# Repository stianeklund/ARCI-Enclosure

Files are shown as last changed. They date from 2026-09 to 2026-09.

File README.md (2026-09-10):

# ARCI Enclosure

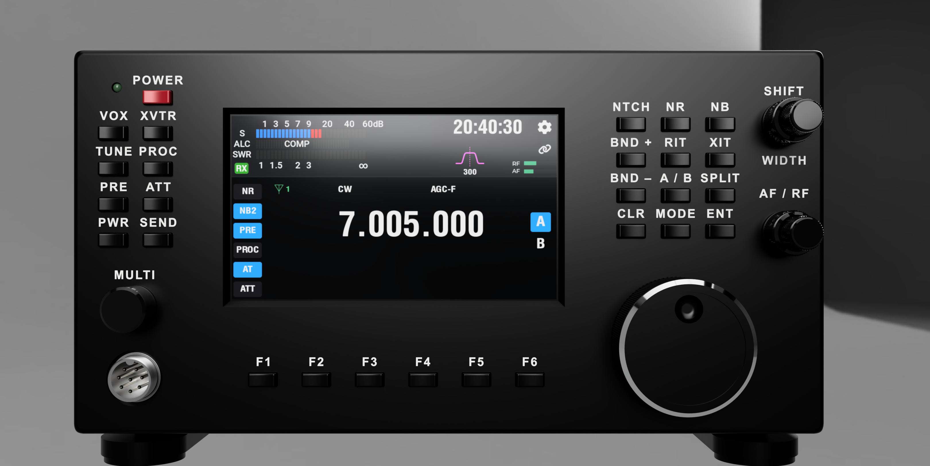
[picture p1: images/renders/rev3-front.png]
ARCI enclosure front view


ARCI Enclosure is a 3D-printable desktop control console for the
[ARCI](https://github.com/stianeklund/ARCI) amateur-radio control interface.
It holds a 5-inch touchscreen, physical controls, and rear I/O connectors.

Revision 3 uses a parametric design unlike the first prototypes which became a Fusion 360 monstrosity..
Print the main shells on a printer with a build area of at least 256 × 256 mm.

## Features

- Two-piece snap-fit enclosure with front and rear shells
- 45° beveled opening for the Waveshare 5-DSI-TOUCH-A display
- Button matrices, function buttons, and rotary encoder openings
- Label inlays for multi-material printing and printable knurled knobs
- Rear I/O openings for USB, RS-232 (DB9), and Wi-Fi/COM connectors
- Internal mounts for the ARCI PCB, display, and optional USB hub
- M3 and M5 mounting points for assembly
- Adjustable rear tilt stand with 15° click-stop increments

The rear connector layout may change.

## Key specifications

| Item | Specification |
| --- | --- |
| Overall dimensions | 254 × 130 × 54 mm |
| Minimum printer build area | 256 × 256 mm |
| Display | Waveshare 5-DSI-TOUCH-A (MIPI DSI), connected to a ESP32-P4-Wifi6 (Pico?) |
| Main controller | ARCI ESP32-S3 PCB |
| Stand adjustment | 15° increments |

## Build and files

1. Review the [bill of materials](BOM.md).
2. Follow the [printing guide](docs/printing.md).
3. Use the [tilt-stand instructions](docs/tilt-stand.md).

The printable files are in [`export/3mf`](export/3mf). Each 3MF is one
separate print part: shells, knobs, button caps, stand pieces, and mounts are
never bundled as an assembled print job. Matching neutral-CAD part files are
in [`cad/step`](cad/step).

For carry cases, accessory design, and visual fit checks, export the separate
non-printable [`ARCI_ENCLOSURE_INSPECTION.step`](cad/assembly/ARCI_ENCLOSURE_INSPECTION.step)
from the Fusion master. It contains the installed project-authored enclosure,
controls, stand, and Waveshare-compatible display replica; it is not a slicer
input and is intentionally separate from the per-part STEP files.

For the optional USB-hub parts, see the
[USB-hub parts guide](docs/right-matrix-usb-hub-shim.md).

## Display compatibility

The current release supports the Waveshare 5-DSI-TOUCH-A display. The Sunton
ESP32-8048S050C is a fit-check variant only and is not part of this release, but future releases will re-add compatability for this display type.

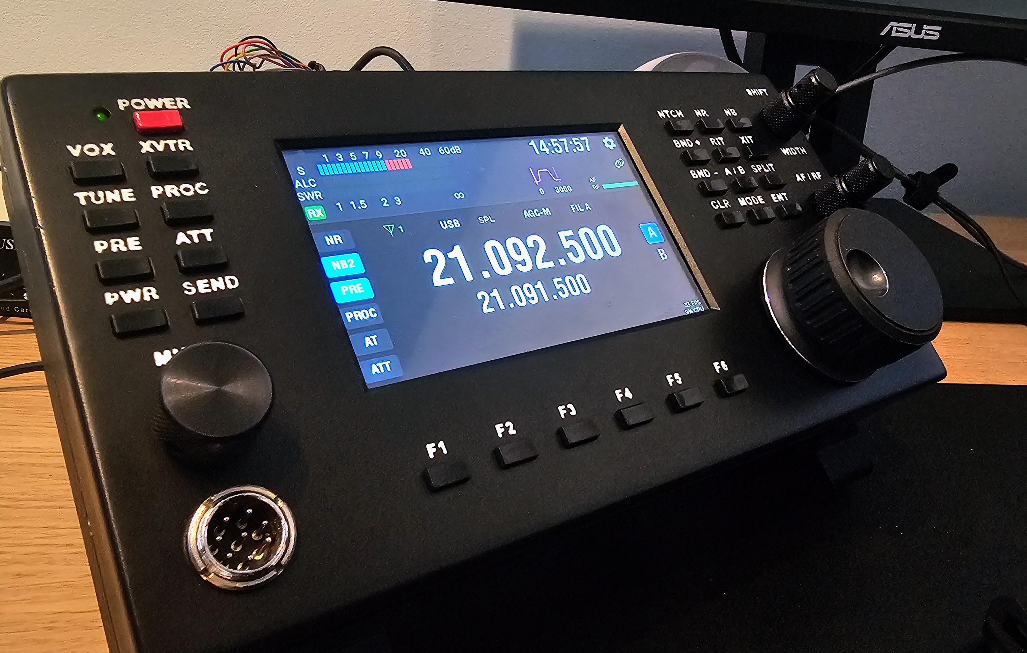
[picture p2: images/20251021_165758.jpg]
Finished enclosure


## Related projects

- [ARCI](https://github.com/stianeklund/ARCI) — firmware and CAT command router
- [ARCI-PCB](https://github.com/stianeklund/ARCI-PCB) — controller PCB
- [RemoteRadioDisplay](https://github.com/stianeklund/RemoteRadioDisplay) — display firmware

## License

This project uses the GPL-3.0 license. See [LICENSE](LICENSE) and
[NOTICE.md](NOTICE.md).

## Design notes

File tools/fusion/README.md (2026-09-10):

# Fusion 360 maintainer tools

This folder contains Fusion 360 scripts for maintainers of the ARCI enclosure.
End users normally need only the printable files in `export/3mf`, the neutral
CAD files in `cad/step`, and the project documentation.

The repository does not contain the private Fusion master. These scripts
rebuild the published parts and create the public release files.

## Before you run a rebuild

The rebuild scripts change the active Fusion document. Use a new working copy
or save a version before you run them. The scripts do not restore the model if
a later step fails.

Start with a parametric Fusion design whose name starts with `ARCI Enclosure
Rev3`. Create these empty root-level components before you run the first
script:

1. `FRONT_HALF`
2. `BACK_HALF`

The scripts expect this component structure. Do not add a body named
`FRONT_SHELL` before you run the first script.

## Install a script bundle

Every public script is a Fusion bundle: its folder contains a same-named
`.py` file and `.manifest`. In **Utilities → Add-Ins → Scripts and Add-Ins**,
open **Scripts**, click **+**, and select the script folder (not the `.py`
file). Install each required bundle once; it remains available in Fusion's
Scripts list thereafter.

## Supported rebuild sequence

Run the scripts in `rebuild/` in this order:

1. `Front_Parametric_Rebuild/`
2. `Front_Internal_Supports_Add/`
3. `Front_Panel_Caps_LED_And_Materials/`
4. `Back_Parametric_Rebuild/`
5. `Multi_Knob_Build/`
6. `Dual_Encoder_Knobs_Build/`
7. `Tilt_Stand_Build/`
8. `Stand_Hardware_Build/`

Run a complete rebuild in a new working document. Some scripts stop when they
find existing geometry. Other scripts replace their earlier script-owned
components.

`options/Build_Right_Matrix_Hub_Cradle/` creates the optional USB-hub cradle.
It is not required for the base enclosure.

## VFO dimple sizing repair

The VFO main knob belongs to the private master, rather than the supported
clean-rebuild set.  If its circular finger dimple loses its curved floor after
editing `vfoDimpleD`, add and run the `rebuild/VFO_Dimple_Parameterize` script
folder once with the master open.  Thereafter, edit only `vfoDimpleD` for ordinary sizing; the
script derives the dimple depth and floor-round radius so the cup keeps its
original 2 mm flat floor and tangent curved sides.  Use a diameter greater
than `vfoDimpleFloorD`.

## Audit and export

Install each release script separately in Fusion:

1. Open **Utilities → Add-Ins → Scripts and Add-Ins → Scripts → +**.
2. Add `release/Fusion_Timeline_Audit`.
3. Add `release/Export_Repository_Artifacts`.

Before you export, review the repository changes. The exporter replaces the
published 3MF and STEP files when it completes successfully.

1. Run `Fusion_Timeline_Audit` on the active release design.
2. Read the report in `docs/generated/fusion_timeline_audit.md`.
3. Resolve every release-gate failure.
4. Run `Export_Repository_Artifacts`.

The audit creates `docs/generated` if needed. It writes a Markdown and JSON
report there. On failure, it writes an error report in the same directory. The
exporter checks the active design again. It exports only the named public parts
in its manifest to `export/3mf` and `cad/step`.

The exporter does not export a full assembly, vendor reference geometry, or an
ECAD model. Neither release script saves the Fusion document.

## Scope and requirements

This public folder excludes private migration, experimental, quality-assurance,
and development-asset tools. Those tools are not part of the supported rebuild
or release process.

The scripts locate the repository from their own file paths. You can use any
checkout location. They require Fusion 360 and its Autodesk Fusion API
(`adsk`).

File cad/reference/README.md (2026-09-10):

# Engineering references

These files support measurement, fit checks, and historical reconstruction.
They are not production exports and are not required to print the enclosure.

- `legacy/` contains source geometry used to reconstruct the native enclosure.
- `waveshare/` contains independently modeled display reference geometry. See
  the repository [NOTICE](../../NOTICE.md) for provenance and trademark notes.

`cad/step/` contains the supported isolated-part neutral-CAD exports.
`cad/assembly/` contains separately exported, non-printable project-authored
inspection assemblies. Neither directory includes the historical references in
this folder.

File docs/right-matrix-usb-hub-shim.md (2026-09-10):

# Optional USB-hub parts

These parts support an optional internal USB hub. They are not required for the
core enclosure.

The design uses a nominal 40 × 30 × 1.6 mm hub PCB. Actual boards can differ.
Check your hub, connectors, and cables before installation.

## Available parts

| Part | Quantity | File |
| --- | ---: | --- |
| Right-matrix open cradle | 1 | [`HUB_RIGHT_MATRIX_OPEN_CRADLE_PLA.3mf`](../export/3mf/HUB_RIGHT_MATRIX_OPEN_CRADLE_PLA.3mf) |
| Upper retainer | 1 | [`HUB_RETAINER_UPPER.3mf`](../export/3mf/HUB_RETAINER_UPPER.3mf) |
| Lower retainer | 1 | [`HUB_RETAINER_LOWER.3mf`](../export/3mf/HUB_RETAINER_LOWER.3mf) |
| Rear tray | 1 | [`HUB_REAR_TRAY.3mf`](../export/3mf/HUB_REAR_TRAY.3mf) |

Select only the parts that match your installation.

## Right-matrix cradle

The cradle mounts above the right button matrix. It uses the four existing M3
mounting axes.

Two end webs connect the matrix standoffs. Side rails and transverse rails
support the hub PCB. The open center gives access to the matrix harness.

The cradle supports four hub orientations. Rotate the hub in 90° increments to
select the best cable direction.

The original orientation puts the three output ports toward the larger cable
space. It puts the USB input and power input toward the top.

## Checked clearances

| Item | Position or size |
| --- | --- |
| Matrix PCB rear face | Y = 12.72 mm |
| Matrix plug keep-out | Y = 12.72 to 23.02 mm |
| Seat-rail underside | Y = 27.70 mm |
| Hub PCB support plane | Y = 30.70 mm |
| Hub envelope | Y = 30.70 to 35.70 mm |
| Rear-cover inner surface | Approximately Y = 50.04 mm |
| Hub PCB | 40 × 30 × 1.6 mm |
| Width across USB-C plugs | 32 mm |

Clearance checks found no solid intersection at any of the four cradle
orientations. The checks included the shells, boards, carrier, hub, and cradle.

The hub envelope comes from photographs and caliper measurements. It is not a
manufacturer CAD model.

## Hardware

Use four M3 × 20 mm screws for the cradle. Check the screw engagement against
the actual matrix stack.

Use M2 fasteners for the hub-retainer positions. Select the length for your hub
board and captive nuts.

Use six M3 × 6 mm screws for the rear tray and retainers. Check the complete
hardware stack before installation.

## Printing

The cradle 3MF has its flat seat face on the build plate. The cradle does not
require generated support material.

Follow the [printing guide](printing.md) for general material and inspection
instructions.

## Files

- [Cradle STEP file](../cad/step/HUB_RIGHT_MATRIX_OPEN_CRADLE_PLA.step)
- [Assembly image](visual-reference/right-matrix-usb-hub-recessed-cradle.png)

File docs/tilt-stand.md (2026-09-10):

# Tilt stand

The stand is a pair of identical hinged supports mounted to the rear shell.
Each side uses one bracket, one support, two rubber foot pads, two M3 mounting
screws, and one M5 hinge fastener set.

## Print and prepare

Print two of each rigid part in PLA or PETG:

- [`STAND_BRACKET.3mf`](../export/3mf/STAND_BRACKET.3mf)
- [`TILT_STAND_SUPPORT.3mf`](../export/3mf/TILT_STAND_SUPPORT.3mf)

Print two of each foot pad in TPU, or replace them with suitable stick-on
rubber pads:

- [`TILT_STAND_FOOT_PAD_NEAR_HINGE.3mf`](../export/3mf/TILT_STAND_FOOT_PAD_NEAR_HINGE.3mf)
- [`TILT_STAND_FOOT_PAD_FAR_FROM_HINGE.3mf`](../export/3mf/TILT_STAND_FOOT_PAD_FAR_FROM_HINGE.3mf)

Print the bracket on its flat mounting face and the support on its foot. Ream
the hinge bores gently to 5.4 mm after printing if needed; the parts should
rotate freely before the hinge is tightened.

## Hardware per side

- 2 × M3 × 12 countersunk screws
- 1 × M5 × 30 hex bolt
- 1 × M5 washer
- 1 × M5 nyloc nut

## Assembly

1. Attach a bracket to each pair of rear-shell pilots with the two M3 screws.
2. Place the support between the bracket ears and align the serrated hinge
   faces at the desired angle.
3. Install the M5 bolt, washer, and nyloc nut. Tighten only enough to engage
   the hinge teeth securely; the support must still be adjustable.
4. Fit one near-hinge and one far foot pad to each support.

The rear shell carries the mounting bosses; neither shell requires extra
fasteners at its snap-fit joint. STEP references are available as
[`STAND_BRACKET.step`](../cad/step/STAND_BRACKET.step),
[`TILT_STAND_SUPPORT.step`](../cad/step/TILT_STAND_SUPPORT.step), and the two
separate foot-pad STEP files. This mirrors the print files: the support and
each pad are independently addressable parts, not a combined assembly export.

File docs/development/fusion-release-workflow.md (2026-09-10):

# Fusion release workflow

The editable master remains a parametric Fusion document. The public release
directories contain only release-safe artifacts: project-authored print files
in `export/3mf`, isolated neutral exchange files in `cad/step`, and an
explicitly curated project-authored inspection assembly in `cad/assembly` when
one is exported. Reference assets and unsupported maintainer tooling remain
private. Do not check in a full assembly archive: it can contain vendor and
ECAD reference models that are excluded from redistribution.

## Timeline policy

Keep the timeline in this order and collapse each group once it is complete:

1. `DATUMS AND PARAMETERS` — component origins, named planes, global user parameters.
2. `FRONT HALF - MECHANICAL` and `BACK HALF - MECHANICAL` — shell, cavity, mating interface, and panel cutouts.
3. `INTERFACES - CARRIERS AND MOUNTS` — display, hub, and electronics-specific printed parts.
4. `BACK HALF - STAND BOSSES AND PILOTS`, then `STAND PARTS` and `ASSEMBLY - TILT STAND`.
5. `PRINT - ...` — deboss and AMS inlay features. Keep these collapsed and suppress them while editing mechanics if Fusion performance requires it.
6. `REFERENCE - ...` — imported/vendor geometry, hidden and never included in a release export.

One group should cover one responsibility and one contiguous timeline range.
Avoid end-of-timeline `Move` / `Align` features in the release master: fix
orientation in the driving datum or keep presentation moves in a separate
document. The exporter publishes only bodies directly owned by each named
component, not positioned occurrences, child inspection components, or the
full assembly. This keeps controls, LEDs, display models, and vendor/ECAD
references useful in the master without putting them in a printable part or
part-level STEP file.

## Release checklist

1. Open the intended parametric master and move the timeline marker to the end.
2. In **Utilities → Add-Ins → Scripts and Add-Ins**, select the **Scripts** tab. Click the `+` button and choose **Script or add-in from device**, then select `tools/fusion/release/Fusion_Timeline_Audit`. Fusion remembers this link, so this is a one-time step. Click **Run** for `Fusion_Timeline_Audit`.
3. Read both `docs/generated/fusion_timeline_audit.md` and `docs/generated/fusion_timeline_audit.json`. These are ignored local working reports: JSON is the automation contract and Markdown is the review record. Attach the passing reports to a release or CI record when evidence must be retained; do not commit a failing or machine-specific snapshot.
4. Resolve every gate failure. The 42 named active-master release-driving sketches are evaluated per entity role, not solely by Fusion's sketch aggregate flag. This includes `ACTIVE_ROOT / SK_DISPLAY_RECESS`, `FRONT_HALF / SK_FRONT_ROTARY_RECESSES_DEEP`, and `FRONT_HALF / SK_FRONT_ROTARY_THROUGH`, which directly drive `FRONT_SHELL`. `PARAMETRIC_DRIVING` is the preferred standard: every release curve participates in driving dimensions/geometric constraints or is a reference/projected/linked curve driven upstream. Offset-constraint outputs are recognized where Fusion exposes their entities. If Fusion's aggregate solver reports fully constrained and there are no true orphans, the audit accepts `PARAMETRIC_DRIVING` with an explicit aggregate-fallback marker when per-entity API mapping is opaque. Independent points that participate in those driving relations are permitted parametric datum helpers. `LOCKED_LEGACY` passes only when every release curve is explicitly fixed and there are no independent/unconnected non-reference sketch points; it is stable but remains a visible technical-debt warning, not the preferred editable standard. `HYBRID_DRIVING_LOCKED` also passes when every curve is covered by the union of explicit fixes and driving dimensions/geometric constraints; it is likewise technical debt and should be converted to fully parametric driving when practical. `ORPHAN_ENTITY` and `FREE_DRIVING` fail. Curve-owned endpoints, centers, spline handles, origins, and reference points do not count as orphan points.
5. The only active-master `REFERENCE_EXCEPTION` pairs are `ACTIVE_ROOT / SK_CANONICAL_DATUM_POINTS`, `LEFT_BUTTON_MATRIX_HARNESS / SK_LEFT_MATRIX_RIBBON_PATH`, and `8PIN_PANEL_CONNECTOR_REFERENCE / SK_GX16_8PIN_CORRECTED_FRONT_PROFILE`; their rationales and evidence are emitted in the audit. `ACTIVE_ROOT` means Fusion's actual `design.rootComponent`, never its mutable document/version display name. Any additional active-master sketch with an orphan/free role fails as **unclassified** until it receives an exact policy decision.
6. Linked-document sketches—including TL3301, EC11E, PEC11R, RMS20, Waveshare, and any other externally referenced document—are reported with occurrence provenance, visibility, aggregate state, and entity-role evidence but are outside the active-master constraint gate. Hide visible linked occurrences for a focused review when practical; this is advisory-only because the exporter writes exact named project-owned component/body targets and never exports full assemblies or occurrences. Confirm the timeline marker is at the end, every timeline group is collapsed, and no release-relevant active-master component contains a `Move` or `Align` feature.
7. Link `tools/fusion/release/Export_Repository_Artifacts` using the same `+` button. Click **Run** only after the audit passes. The exporter repeats the same in-memory gate immediately before writing, so a stale clean report cannot authorize an overwrite.
8. The per-part exporter may write only its allowlisted public contract: 17 named 3MF files under `export/3mf` and 17 matching per-part STEP files under `cad/step`. Component artifacts contain only that component's directly owned bodies, so a `FRONT_HALF` export contains the shell and its `INLAY_*` bodies but not nested knobs, caps, LEDs, display models, vendor models, or ECAD references. This applies identically to 3MF and STEP. The shell must carry a black appearance and every `INLAY_*` body a white appearance; staged 3MF validation rejects missing shell/inlay bodies or black/white colours. The two stand sides must pass the exporter's topology-and-size equivalence signature before the positive-side bracket/support definitions can serve as their canonical manufacturing source; otherwise the exporter requires handed artifacts. `WIFI6_REAR_HOLDER` is not part of this contract unless it is deliberately restored to the master, documented, and audited.
9. Use `tools/fusion/release/Export_Inspection_Assembly` only when a positioned, non-printable STEP is wanted for a carry case or other accessory. It exports all project-authored native bodies in their installed positions to `cad/assembly/ARCI_ENCLOSURE_INSPECTION.step` and deliberately excludes linked supplier components. It is a separate contract from the per-part exports; never send it to a slicer.
10. Open each changed 3MF in the target slicer; validate part count, orientation, and the black-shell / white-`INLAY_*` body assignment. Open the changed per-part STEP files and, when generated, the inspection STEP in a neutral CAD viewer as a final geometry check.
11. Review `git diff --stat` and commit only the generated public artifacts and related documentation. Do not add vendor, ECAD, temporary inspection, or ignored Fusion archive files.

The exporter generates and validates the complete set in an ignored,
same-filesystem staging directory before it touches public paths. It backs up
existing artifacts during promotion and attempts a full rollback if promotion
fails, preventing an ordinary mid-export failure from leaving a partial set.

The scripts intentionally fail if a named release component/body is missing or
duplicate; if the timeline is rolled back; or if the shared quality gate finds
active-master unhealthy features, unresolved/stale policy, required
`ORPHAN_ENTITY`/`FREE_DRIVING` roles, unclassified active-master orphan/free
sketches, expanded groups, or release-relevant active-master Move/Align
features. `LOCKED_LEGACY` and
`HYBRID_DRIVING_LOCKED` pass with visible technical-debt warnings.
Linked-document findings and visibility remain visible as audit advisories but
do not block the active-master release gate. That turns a silent stale or
incomplete export into an actionable release failure.

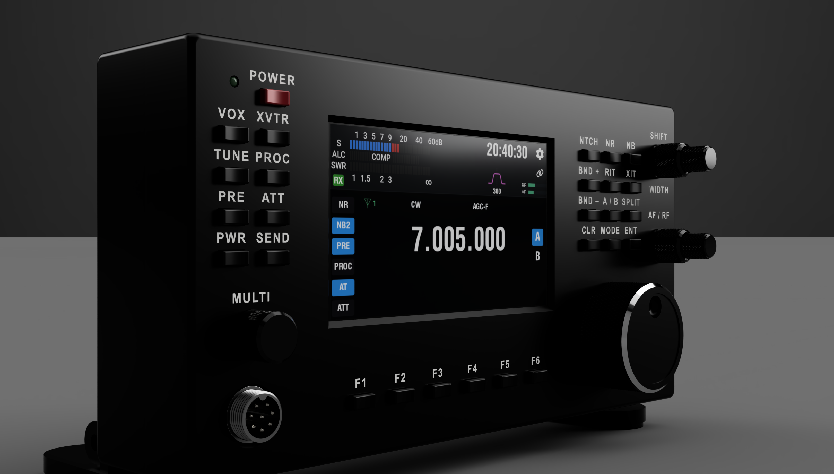
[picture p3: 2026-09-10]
images/renders/rev3-front-three-quarter.png

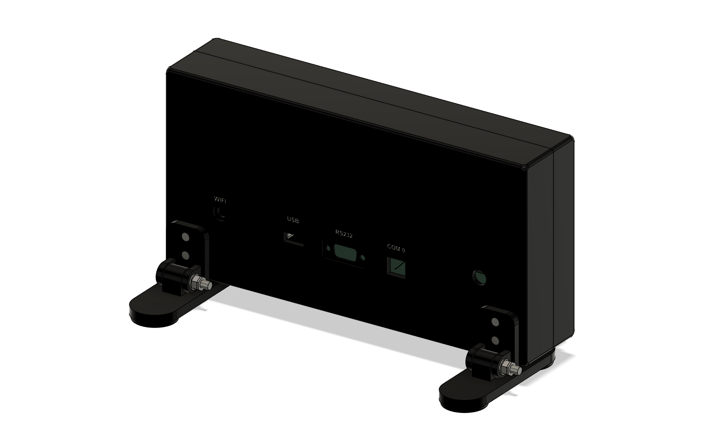
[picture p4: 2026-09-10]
images/renders/rev3-rear-three-quarter.png

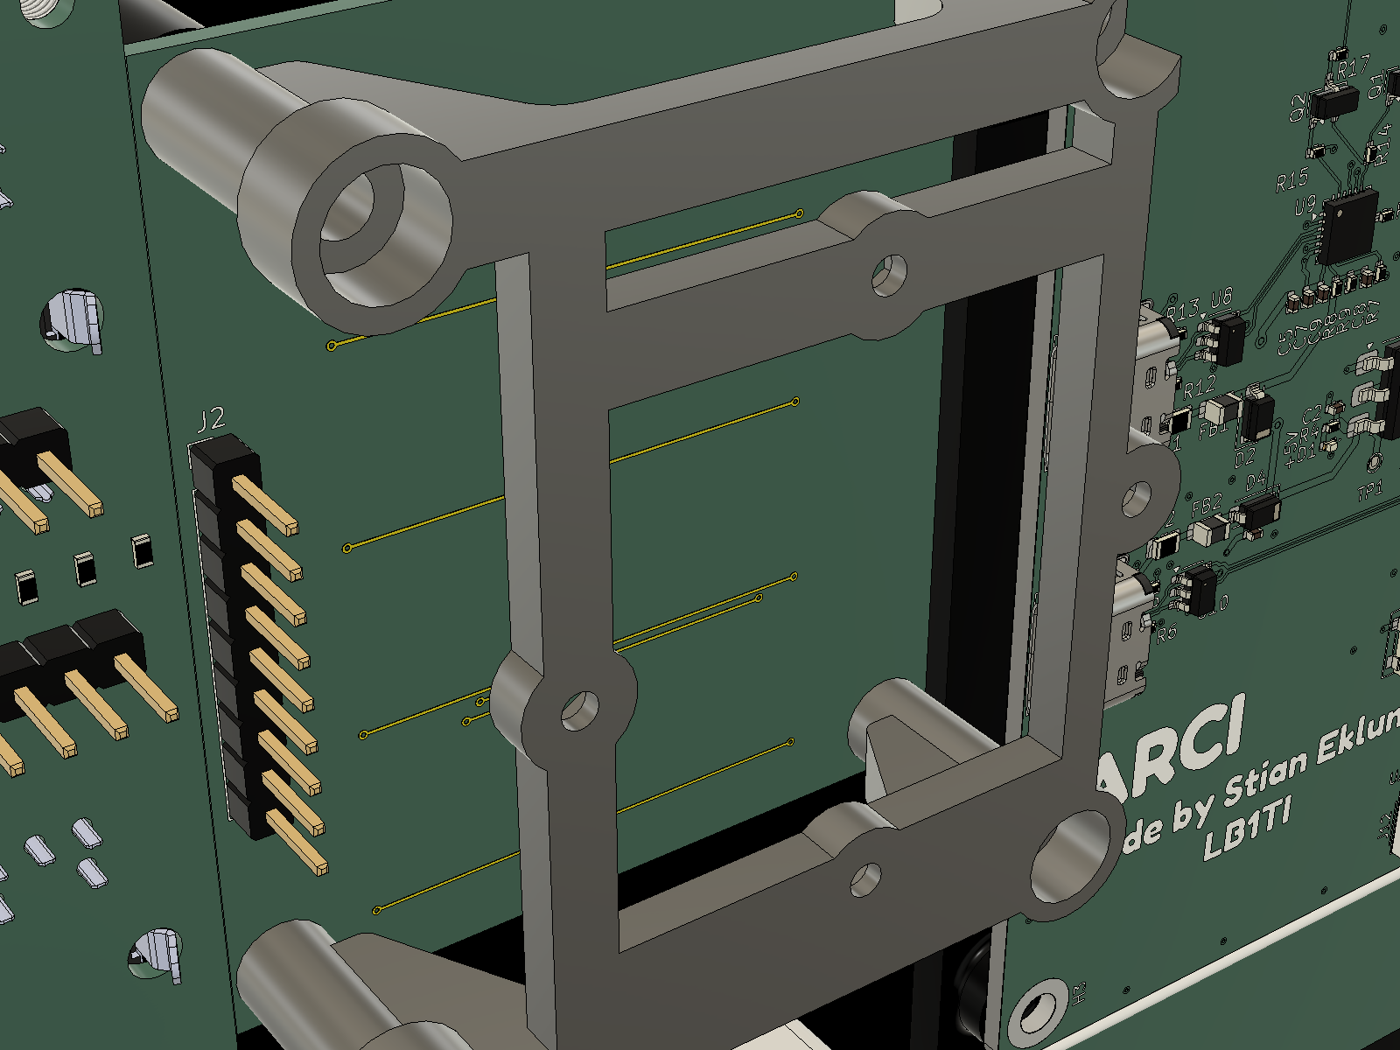
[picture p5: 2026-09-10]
docs/visual-reference/right-matrix-usb-hub-recessed-cradle.png

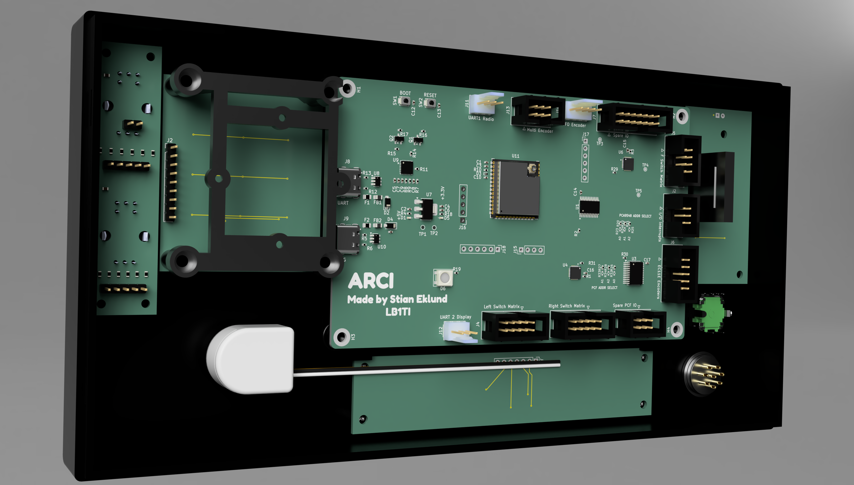
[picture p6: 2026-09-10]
images/renders/rev3-front-inside.PNG

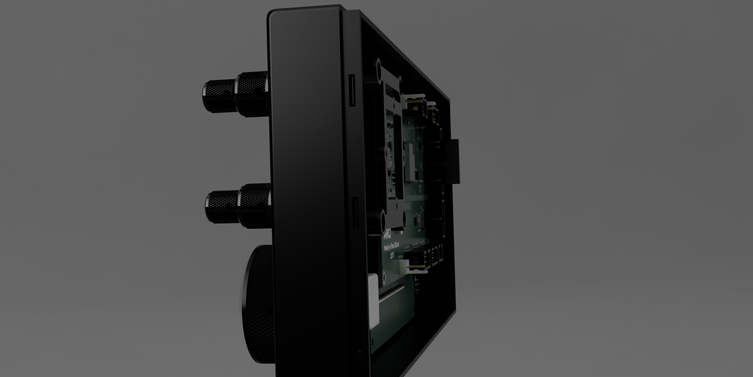
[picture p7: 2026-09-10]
images/renders/rev3-snap-fit.PNG

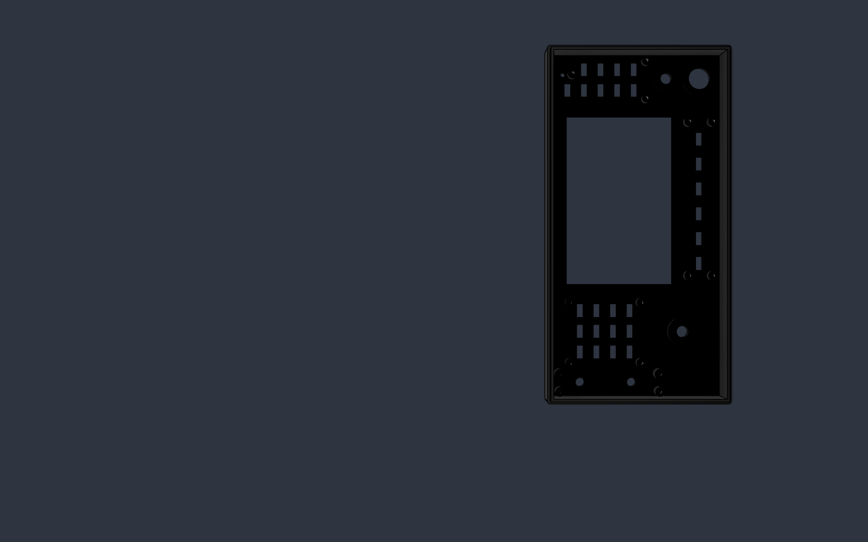
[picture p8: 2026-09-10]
docs/visual-reference/original-front-interior-back.png

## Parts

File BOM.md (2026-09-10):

# ARCI Enclosure bill of materials

This bill of materials covers the parts necessary to build the enclosure.
It describes the mechanical package and the hardware needed to populate it; it does not replace the PCB-specific BOMs.

## Printed parts

The supported core print set is listed below. See the [printing guide](docs/printing.md) for material and orientation guidance.

| Part | Quantity | File | Status |
| --- | ---: | --- | --- |
| Front enclosure with label inlays | 1 | [`FRONT_HALF.3mf`](export/3mf/FRONT_HALF.3mf) | Supported core part |
| Back enclosure with label inlays | 1 | [`BACK_HALF.3mf`](export/3mf/BACK_HALF.3mf) | Supported core part |
| MULTI/CH knob | 1 | [`KNOB_MULTI.3mf`](export/3mf/KNOB_MULTI.3mf) | Print separately |
| Dual-encoder outer knob | 2 | [`KNOB_DUAL_OUTER_15.3mf`](export/3mf/KNOB_DUAL_OUTER_15.3mf) | AF/RF and IF-shift outer controls |
| Dual-encoder inner knob | 2 | [`KNOB_DUAL_INNER_11.3mf`](export/3mf/KNOB_DUAL_INNER_11.3mf) | AF/RF and IF-shift inner controls |
| VFO knob core | 1 | [`KNOB_VFO_CORE.3mf`](export/3mf/KNOB_VFO_CORE.3mf) | Print separately |
| VFO grip sleeve | 1 | [`KNOB_VFO_GRIP.3mf`](export/3mf/KNOB_VFO_GRIP.3mf) | Flexible grip material recommended |
| Button cap | 27 | [`BUTTON_CAP.3mf`](export/3mf/BUTTON_CAP.3mf) | Print separately; POWER cap uses red filament |
| Waveshare display carrier | 1 set | [`DISPLAY_CARRIER_WAVESHARE_ARCI.3mf`](export/3mf/DISPLAY_CARRIER_WAVESHARE_ARCI.3mf) | Supported core part |
| Stand bracket | 2 | [`STAND_BRACKET.3mf`](export/3mf/STAND_BRACKET.3mf) | Supported core part |
| Stand support | 2 | [`TILT_STAND_SUPPORT.3mf`](export/3mf/TILT_STAND_SUPPORT.3mf) | Supported core part |
| Near-hinge foot pad | 2 | [`TILT_STAND_FOOT_PAD_NEAR_HINGE.3mf`](export/3mf/TILT_STAND_FOOT_PAD_NEAR_HINGE.3mf) | TPU or rubber alternative |
| Far foot pad | 2 | [`TILT_STAND_FOOT_PAD_FAR_FROM_HINGE.3mf`](export/3mf/TILT_STAND_FOOT_PAD_FAR_FROM_HINGE.3mf) | TPU or rubber alternative |

Optional USB-hub files are listed in the [USB-hub notes](docs/right-matrix-usb-hub-shim.md).

## Core electronics and controls

| Item | Quantity | Notes |
| --- | ---: | --- |
| ARCI main PCB | 1 | Control board; see [ARCI-PCB](https://github.com/stianeklund/ARCI-PCB). |
| Waveshare 5-DSI-TOUCH-A display | 1 | Current preferred display. |
| Waveshare ESP32-P4-Wifi6 | 1 | Connected to the display via MIPI DSI. |
| Left button-matrix PCB | 1 | Link and PCB-specific BOM still to be added. |
| Right button-matrix PCB | 1 | Link and PCB-specific BOM still to be added. |
| Function-key PCB | 1 | Link and PCB-specific BOM still to be added. |
| AF/RF encoder PCB | 1 | Part of the current control assembly. |
| Dual-shaft rotary encoders | 2 | `EC11EBB24C03` or `EC110701N2B` have been used successfully, sourced from AliExpress or similar. |
| MULTI/CH encoder | 1 | I just used a KY-040? type encoder that I had laying around, most encoders work here but take into consideration the shaft length |
| VFO encoder | 1 | Most encoders will work, I opted to use a real RMS20-250-201 by Nidec Copal |

## Buttons and caps

The front panel has 27 button positions. Final quantities must follow the finalized left/right matrix and function-key PCB designs.

| Item | Known part | Notes |
| --- | --- | --- |
| Surface-mount tactile switch | `TL3301SPF160QG` | Purchase part only. Alternatives must match the PCB footprint. |
| Keycaps | As required | DigiKey part numbers: EG1181-ND, and EG1185-ND made by E-Switch |
| Encoder caps | [Aluminum cap reference](https://www.aliexpress.com/item/1005009504767268.html) | These are suprisingly nice. |

In theory it's possible to print key caps as well, the reference model is printable and should work, but I prefer the real deal.

## Enclosure installation hardware

| Assembly | Quantity | Hardware | Notes |
| --- | ---: | --- | --- |
| Shell joint | — | None | The front and rear shells use the integrated snap fit. Assembled overlap is 5.96 mm; mating-groove depth is 6.10 mm. |
| ARCI PCB to display carrier | 4 | M3 × 8–10 mm screws | Confirm length against the final PCB stack and any washers. |
| Waveshare display to carrier | 4 | M2.5 machine screws | Confirm exact length during physical carrier fit testing. |

## Tilt stand

The stand uses two printed brackets, two supports, and four rubber or TPU pads. See [Tilt stand](docs/tilt-stand.md) for printing and assembly.

| Part | Quantity | Specification |
| --- | ---: | --- |
| Bracket screw | 4 | DIN 965 M3 × 12 countersunk |
| Hinge bolt | 2 | DIN 931 M5 × 30 hex bolt; 14 mm plain shank |
| Hinge washer | 2 | DIN 125; 10 × 5.3 × 1 mm |
| Hinge nut | 2 | DIN 985 M5 nyloc; AF 8 mm |
| Foot pads | 4 | Ø28 × 3 mm TPU pads or stick-on rubber equivalent |

## Optional USB-hub and rear-mount hardware

| Assembly | Hardware | Notes |
| --- | --- | --- |
| Right-matrix USB hub cradle | 4 × M3 × 20 mm screws | The cradle uses the matrix mounting axes. Verify actual matrix stack height. |
| Hub retainers | M2 screws or captive-nut hardware as required | Confirm the actual hub board, hole pattern, and screw length. |
| USB hub tray and retainers | 6 × M3 × 6 mm screws | Optional rear mount; verify the hardware stack. |

- The internal USB hub is optional. The cradle is based on a nominal [40 × 30 mm USB hub reference](https://www.aliexpress.com/item/1005009383595449.html); verify the actual board and connector clearances before installation.
- Use suitably short internal USB cables. Check bend radius and plug clearance with the enclosure closed; one [cable reference](https://www.aliexpress.com/item/1005006806265814.html) is available, but cable selection is installation-specific.
- The modeled 8-pin circular rear connector is cosmetic. Select a real connector only if that interface is required.
- Modeled encoder and connector envelopes are neutral fit-check geometry, not manufacturer CAD files. Verify the actual clone or supplier part before printing.

## Still to specify

- Links and final BOMs for the button-matrix and function-key PCBs.
- Exact Waveshare M2.5 screw length after a physical carrier fit check.
- The final rear-connector set and cable harness.

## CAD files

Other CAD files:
cad/reference/waveshare/Waveshare_5_DSI_TOUCH_A.step
cad/step/KNOB_VFO_CORE.step
cad/step/KNOB_VFO_GRIP.step
cad/step/TILT_STAND_SUPPORT.step
cad/step/Front_Half.step
cad/step/TILT_STAND_FOOT_PAD_FAR_FROM_HINGE.step
cad/step/BUTTON_CAP.step
cad/step/KNOB_MULTI.step
cad/step/HUB_REAR_TRAY.step
cad/step/BACK_HALF.step
cad/step/KNOB_DUAL_OUTER_15.step
cad/step/KNOB_DUAL_INNER_11.step
cad/step/HUB_RETAINER_LOWER.step
cad/step/HUB_RIGHT_MATRIX_OPEN_CRADLE_PLA.step
cad/step/DISPLAY_CARRIER_WAVESHARE_ARCI.step
cad/step/HUB_RETAINER_UPPER.step
cad/step/TILT_STAND_FOOT_PAD_NEAR_HINGE.step
cad/step/STAND_BRACKET.step
cad/reference/legacy/Back.step
cad/reference/legacy/Front.dxf
cad/reference/waveshare/Waveshare_5_DSI_TOUCH_A.3mf
cad/reference/waveshare/Waveshare_5_DSI_TOUCH_A.f3d
cad/step/TILT_STAND_SUPPORT_AND_FEET.step
export/3mf/BACK_HALF.3mf
export/3mf/BUTTON_CAP.3mf
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

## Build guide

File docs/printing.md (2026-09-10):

# Printing guide

This guide covers the core enclosure parts.
Optional USB-hub parts have
 separate [installation notes](right-matrix-usb-hub-shim.md).

## Printer requirements

Use a 3D printer with a build area of 256 × 256 mm or more.
The front shell measures 254 mm across its longest side.

Use a 0.4mm nozzle & use Arachne wall generation for the best text inlay results.

## Enclosure print files

Print the quantities shown for one enclosure.

| Part | Quantity | File |
| --- | ---: | --- |
| Front enclosure with label inlays | 1 | [`FRONT_HALF.3mf`](../export/3mf/FRONT_HALF.3mf) |
| Back enclosure with label inlays | 1 | [`BACK_HALF.3mf`](../export/3mf/BACK_HALF.3mf) |

`FRONT_HALF.3mf` contains only `FRONT_SHELL` and its `INLAY_FRONT_*` label
bodies. `BACK_HALF.3mf` contains only `BACK_SHELL` and its `INLAY_BACK_*`
label bodies.

## Knobs & buttons

These are entirely optional but in theory should be printable, please see [`BOM.md`](../BOM.md) for details.
The parts are to some degree reference implementations or approximations meant for fitting.

| Part | Quantity | File |
| --- | ---: | --- |
| MULTI/CH knob | 1 | [`KNOB_MULTI.3mf`](../export/3mf/KNOB_MULTI.3mf) |
| Dual-encoder outer knob | 2 | [`KNOB_DUAL_OUTER_15.3mf`](../export/3mf/KNOB_DUAL_OUTER_15.3mf) |
| Dual-encoder inner knob | 2 | [`KNOB_DUAL_INNER_11.3mf`](../export/3mf/KNOB_DUAL_INNER_11.3mf) |
| VFO knob core | 1 | [`KNOB_VFO_CORE.3mf`](../export/3mf/KNOB_VFO_CORE.3mf) |
| VFO grip sleeve | 1 | [`KNOB_VFO_GRIP.3mf`](../export/3mf/KNOB_VFO_GRIP.3mf) |
| Button cap | 27 | [`BUTTON_CAP.3mf`](../export/3mf/BUTTON_CAP.3mf) |

The two inner/outer knob pairs serve the AF/RF-gain and IF-shift controls as the encoders are dual axis encoders.

## Mounts and stand

| Part | Quantity | File |
| --- | ---: | --- |
| Display carrier / bracket | 1 set | [`DISPLAY_CARRIER_WAVESHARE_ARCI.3mf`](../export/3mf/DISPLAY_CARRIER_WAVESHARE_ARCI.3mf) |
| Stand bracket | 2 | [`STAND_BRACKET.3mf`](../export/3mf/STAND_BRACKET.3mf) |
| Stand support | 2 | [`TILT_STAND_SUPPORT.3mf`](../export/3mf/TILT_STAND_SUPPORT.3mf) |
| Near-hinge foot pad | 2 | [`TILT_STAND_FOOT_PAD_NEAR_HINGE.3mf`](../export/3mf/TILT_STAND_FOOT_PAD_NEAR_HINGE.3mf) |
| Far foot pad | 2 | [`TILT_STAND_FOOT_PAD_FAR_FROM_HINGE.3mf`](../export/3mf/TILT_STAND_FOOT_PAD_FAR_FROM_HINGE.3mf) |

The stand / hinged feet are not a print in place model, you need to the parts separately.

## Materials

I recommend to use PLA, but I'm sure PETG could be used or similar materials.
I also haven't actually tried this but you could probably use TPU for the foot pads and similarly for the VFO encoder "sleeve".

## Part orientation

- Put each stand bracket on its flat mounting face.
- Put each stand support on its foot.
- Orient knobs and caps so their visible faces are upward and their bores do
  not require unsupported bridging.
- Keep the supplied orientation for the other 3MF files.

## Front-panel text

Use Arachne wall generation for the small front-panel text. Check each label in
the slicer preview.

Use a multi-material print for the integrated white text. You can also paint
the recessed text after printing.

The exporter refuses to publish a front or rear 3MF unless it contains both
the black shell and white label-body colours. If a slicer still shows orange,
re-export from Fusion and verify that the imported model has separate shell and
`INLAY_*` bodies before assigning filaments.

See the [tilt-stand instructions](tilt-stand.md) for stand preparation and
assembly.

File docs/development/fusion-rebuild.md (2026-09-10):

# Fusion 360 rebuild and script guide

## Before starting

The scripts require Autodesk Fusion 360 and its `adsk` API. The repository's
STEP, 3MF, and F3D files use Git LFS. The maintained tooling is under
`tools/fusion`.

Each script / tool is made as a Fusion script bundle.
Add its folder from Fusion 360,  **Utilities → Add-Ins → Scripts and Add-Ins → Scripts → +**.

## Supported clean rebuild

Run the scripts in `tools/fusion/rebuild/` in this order against the clean
Fusion design. Run one script at a time and inspect the browser/timeline after
each step.

1. `tools/fusion/rebuild/Front_Parametric_Rebuild/`
2. `tools/fusion/rebuild/Front_Internal_Supports_Add/`
3. `tools/fusion/rebuild/Front_Panel_Caps_LED_And_Materials/`
4. `tools/fusion/rebuild/Back_Parametric_Rebuild/`
5. `tools/fusion/rebuild/Multi_Knob_Build/`
6. `tools/fusion/rebuild/Dual_Encoder_Knobs_Build/`
7. `tools/fusion/rebuild/Tilt_Stand_Build/`
8. `tools/fusion/rebuild/Stand_Hardware_Build/`

`Multi_Knob_Build/` is part of the supported sequence even though the
MULTI/CH knob is a small part. It must not be omitted when reproducing the
complete control layout.

The clean rebuild sequence creates the base mechanical model and supported
stand/control parts.

## Optional parts

`tools/fusion/options/Build_Right_Matrix_Hub_Cradle/` builds the supported
optional USB hub cradle. It is not required for the base enclosure.

## Release audit and export scripts

Use the two Fusion scripts under `tools/fusion/release/` only after the model
has been rebuilt or deliberately migrated:

1. Run `tools/fusion/release/Fusion_Timeline_Audit` with the intended design
   open.
2. Review `docs/generated/fusion_timeline_audit.md` and
   `docs/generated/fusion_timeline_audit.json`.
3. Resolve every release-gate failure. A failing or stale report never
   authorizes an export.
4. Run `tools/fusion/release/Export_Repository_Artifacts` only after the audit
   passes. It emits isolated print parts and matching part-level STEP files;
   it does not emit an assembled front panel.
5. When an accessory-design reference is wanted, run
   `tools/fusion/release/Export_Inspection_Assembly` separately. Its STEP is
   an installed, non-printable project-authored inspection assembly.
6. Inspect changed 3MFs in the target slicer and STEP files in a neutral CAD
   viewer before publishing.

The exporter writes only the named public parts. It does not export a full
assembly, positioned occurrence, vendor model, or ECAD reference. Neither
release script saves the Fusion document. Save a reviewed Fusion version only
after the geometry and timeline changes have been explicitly approved.

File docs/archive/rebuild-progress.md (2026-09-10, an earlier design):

# Historical engineering record: ARCI Enclosure Rev3 reconstruction

> **Archive notice:** This document preserves development measurements and decisions from the reconstruction effort. It is not the current release guide or a statement of the current Fusion master state. Names, version numbers, open issues, and next actions below may be historical. Use the supported [Fusion rebuild guide](../development/fusion-rebuild.md), [release workflow](../development/fusion-release-workflow.md), and the root [README](../../README.md) for current instructions.

Last updated: 2026-09-02

## Goal

Reconstruct both halves of the ARCI enclosure in **ARCI Enclosure Rev3** as a clean, native, performant Fusion 360 design while retaining the dimensions, appearance, control layout, connector layout, and mating behavior of the supplied reference files and the legacy `Radio Enclosure Front - Proto v66` design.

Reference files:

- `Front_Half.step`
- `Back.step`
- `Front.dxf`

The finished design must:

- Match the existing front and back enclosure geometry and dimensions.
- Reproduce the original front/back snap fit and intentional preload.
- Use named user parameters for design-driving dimensions.
- Use small, purpose-specific, fully constrained sketches.
- Keep panel geometry, labels, and lip/notch geometry separate.
- Use model features and feature patterns instead of duplicating large amounts of sketch geometry.
- Remain responsive and straightforward to modify downstream.

## Current Fusion Document

- Active master: `ARCI Enclosure Rev3 v1`. It contains identity-positioned `FRONT_HALF` and `BACK_HALF` components rebuilt natively with +X right, +Z up, and no body-level orientation transform.
- Legacy functional comparison source: `Radio Enclosure Front - Proto v66`. Use this document—not Rev2—as the authority when evaluating which original internal features must be retained.
- Historical mechanical checkpoint: `ARCI Enclosure Rev2 v16`. Do not use it as the functional comparison baseline for missing internal features and do not save over it.
- Orientation proof of concept: one unsaved `Untitled` assembly containing Rev2 as a linked occurrence with a rigid 180° Y-axis transform. It validates the required global transform but is **not** the intended final solution.
- Historical print-preparation checkpoint: `ARCI Enclosure Rev2 - AMS Print Prep v1` (saved and clean). It is no longer part of the maintained workflow and does not need to be synchronized with the master.
- Do not intentionally modify the legacy `Radio Enclosure Front - Proto v66` document.

### V3 internal-support update

- Compared the interior directly with `Radio Enclosure Front - Proto v66`; Rev2 was not used as the missing-feature authority.
- Recreated the five rotary/control support collars in `FRONT_HALF` as three small, purpose-specific parametric sketches and three joined model features.
- The standard collar group reproduces the MULTI, TUNE, and two right-side control collars. The AF/RF collar is modeled separately because it has a deeper stepped bore.
- Added named parameters for all collar outside diameters, through diameters, standard/deep collar lengths, AF/RF counterbore diameter, and AF/RF counterbore depth.
- Grouped the new timeline items as `FRONT HALF - CONTROL SUPPORT COLLARS`.
- Solid-volume cross-check: the five measured annular features total `3,526.6759 mm³`, agreeing within approximately `0.026 mm³` with the `3,526.650 mm³` original-material deficit identified by the earlier Boolean comparison.
- The v66 main front body has no rear guide tunnels extending the rectangular pushbutton openings beyond the 3 mm front wall. None were invented in V3.
- Display mounting/support geometry was added later as the Waveshare carrier (audited 2026-09-02).

### Root-level sketch audit

The three root-level sketches are orientation-remediation point sets, not production profiles:

| Sketch | Contents | Assessment |
| --- | ---: | --- |
| `SK_CANONICAL_DATUM_POINTS` | 5 points; 0 curves, text, or profiles | Retain for now as the canonical orientation datum/reference. |
| `SK_TEST_FRONT_BASIS` | 1 point; 0 curves, text, or profiles | Temporary orientation diagnostic; candidate for later cleanup after a dependency check. |
| `SK_TEST_REAR_BASIS` | 1 point; 0 curves, text, or profiles | Temporary orientation diagnostic; candidate for later cleanup after a dependency check. |

These point-only sketches can appear empty in the canvas and do not materially affect Fusion performance. No sketch was deleted during this audit.

## Orientation Standard

- Canonical front inspection is from negative Y toward positive Y, with **+X to the viewer's right** and **+Z upward**. Fusion's named Front view alone is not sufficient evidence because its camera roll can conceal an axis inversion.
- Positive Y runs from the exterior front face toward the rear of the enclosure.
- The panel datum/origin remains centered.
- Design-driving X and Z values are documented in this canonical front coordinate system.
- The current Rev2 source is globally inverted in X and Z: physical top features such as `POWER` and `SHIFT` are at negative Z, while `F1`–`F6` are at positive Z. Most front/rear face sketches use local X = model +X and local Y = model -Z.
- The required source-to-canonical mapping is the rigid transform `(X, Y, Z) -> (-X, Y, -Z)`, equivalent to a 180° rotation about the depth/Y axis.
- A handedness-changing body mirror is prohibited because it can silently invalidate mating geometry and left/right control placement.

## Ground-Up Orientation Remediation Plan

The final correction must be native to the driving sketches and datums. A linked wrapper, imported solid, body move, or end-of-timeline orientation feature is not an acceptable final master.

### Phase 1 — Freeze and measure the baseline

- Preserve Rev2 v16 as the source checkpoint and do not modify the legacy prototype.
- Record all user parameters, shell volumes/faces, bounding boxes, feature health, sketch constraint state, thread metadata, label strings, and inlay body counts.
- Preserve the verified 254 × 130 mm envelope, 5.96 mm overlap, approximately 8.572 mm³ twelve-zone latch preload, and exact prototype corner topology.
- Record semantic orientation checks: `POWER`/`SHIFT` must finish at positive Z, `F1`–`F6` at negative Z, front-left controls at negative X, and front-right controls at positive X.

#### Captured Rev2 v16 baseline

| Item | Baseline |
| --- | ---: |
| User parameters | 131 |
| Timeline items | 100 |
| Native sketches | 32 |
| Features | 60 |
| Root bodies | 123 |
| Fully constrained sketches | 22 / 32 |
| Unhealthy sketches/features | 0 / 0 |
| Front AMS inlay bodies | 105 |
| Back AMS inlay bodies | 16 |
| `FRONT_SHELL` volume | 140,101.421409 mm³ |
| `FRONT_SHELL` faces | 2,079 |
| `BACK_SHELL` volume | 197,136.051275 mm³ |
| `BACK_SHELL` faces | 519 |

- Core front bounds before any presentation transform: X `[-127, 127]`, Y `[0, 30]`, Z `[-65, 65]` mm.
- Core back bounds before presentation transforms: X `[-127, 127]`, Y `[24.04, 54.04]`, Z `[-65, 65]` mm.
- Final timeline items `Move1` and `Move2` each translate selected back geometry +10 mm in Y for separated presentation, producing displayed back bounds Y `[34.04, 64.04]`. They are not part of the mating geometry and must not be reproduced in the corrected master.
- The native source has 26 XZ face sketches using local X = model +X and local Y = model -Z, plus six notch/detent sketches on orthogonal planes, nine custom construction planes, five rectangular patterns, and two mirrors.

#### Canonical unsaved rebuild validation

| Item | Corrected result |
| --- | ---: |
| Timeline items | 18 (including four audited notch-crown fillets) |
| Front sketches / features | 20 / 27 |
| Back sketches / features | 14 / 21 |
| Unhealthy sketches/features | 0 / 0 |
| Front native text / inlay bodies | 31 / 105 |
| Back native text / inlay bodies | 4 / 16 |
| `FRONT_SHELL` volume before crown fillets | 140,192.557173 mm³ |
| `FRONT_SHELL` volume after crown fillets | 140,193.252874 mm³ |
| `BACK_SHELL` volume | 197,136.065508 mm³ |
| Corrected front/back latch interference | 8.411265699 mm³ across the same twelve zones |

- Both shells retain the exact 254 × 130 mm envelope and canonical bounds: front Y `[0, 30]` mm; back Y `[24.04, 54.04]` mm.
- The back shell differs from the baseline by only `0.014233 mm³`. The front differs by `91.831465 mm³` (`0.0655%`), mainly in simplified front feature construction; no dimensions were intentionally changed.
- The corrected latch interference is `0.161142 mm³` (`1.88%`) below the original 8.572407 mm³ target. The original 45° taper, nominal depths, and R0.4 crown dimensions are retained; do not tune source dimensions merely to force the aggregate Boolean number.
- Fusion standard Front and Back screenshots confirm upright exterior text. Front labels retain `NTCH`, `WIDTH`, and `AF/RF`; rear labels are horizontal, upright, centered on connector X coordinates, and above the openings.
- The 15 pilot cylinders carry one full-length cosmetic ISO M3×0.5 6H thread feature. Helical thread geometry is intentionally not modeled.

### Phase 2 — Establish canonical datums

- Create explicit, named, oriented datum planes for front exterior, rear exterior, top, bottom, left, and right.
- Verify each datum's origin, local X direction, local Y direction, and normal numerically before drawing geometry.
- Front-facing sketches must edit naturally with local right/up corresponding to model +X/+Z. Rear-facing label sketches must edit naturally when viewed from the rear exterior, without corrective text mirroring.
- Keep all enclosure geometry in identity-positioned `FRONT_HALF` and `BACK_HALF` components sharing the same global user parameters.

### Phase 3 — Rebuild the front in canonical coordinates

- Recreate the symmetric outer shell, cavity, lip, relief, and corner treatment from the existing parameter expressions.
- Transform and recreate the display, button, rotary, recess, mounting-boss, pilot-hole, and notch seed sketches using one audited coordinate conversion at the source boundary.
- Recreate pattern and mirror directions explicitly in canonical axes; do not assume a corrected seed automatically fixes a root-axis pattern.
- Recreate the M3×0.5 6H cosmetic thread feature after the pilot-hole geometry is healthy.
- Recreate `SK_LABELS` as upright native text in the corrected front datum, preserving all strings, centers, height parameters, `WIDTH`/`AF / RF` placement, and `NTCH` correction.
- Generate the front deboss and 105 AMS inlay bodies from the corrected native text sketch.

### Phase 4 — Rebuild the back in canonical coordinates

- Recreate the back shell, groove, cavity, connector cutouts, connector recesses, and prototype-matched corner treatment.
- Transform all top/bottom and left/right detent seed positions and verify their extrusion/taper directions in the canonical frame.
- Recreate the four rear labels as upright native text centered on their connector centerlines and above the openings in global +Z.
- Generate the rear deboss and 16 AMS inlay bodies from `SK_BACK_LABELS_NATIVE`.

### Phase 5 — Parametric and geometric validation

- Require every design-driving mechanical sketch to be fully constrained; document intentional non-driving text placement frames separately.
- Confirm zero unhealthy sketches/features and a successful full compute with all timeline items active.
- Exercise width and height parameters away from nominal and restore them, confirming that shells, lip, notches, detents, corner treatment, and labels rebuild predictably.
- Compare the corrected solids against the supplied STEP/DXF references after applying only the documented source alignment.
- Re-run front/back interference analysis and preserve the twelve localized preload zones.
- Confirm front and rear text readability from their respective exterior views, 0.6 mm deboss depth, and exact black/white interface alignment.
- Keep print features grouped and normally suppressed so everyday editing remains responsive.

### Phase 6 — Promotion

- Present the corrected design unsaved for visual inspection with a camera explicitly set to +X right/+Z up.
- Save and promote the corrected document only after explicit approval.
- Archive or discard the linked-wrapper experiment and retire Rev2 only after the corrected master passes every validation gate.

## Reference Geometry Verified

### Overall enclosure

| Item | Value |
| --- | ---: |
| Width | 254 mm |
| Height | 130 mm |
| Front-half depth | 30 mm |
| Outer corner radius | 1.9 mm |
| Back-half start along depth | 24.04 mm |
| Front/back overlap | 5.96 mm |

### Display

Coordinates below are relative to the panel center.

| Item | Value |
| --- | ---: |
| Display center X | -18.5246 mm |
| Display center Z | 11.7106 mm |
| Front opening | 114.42 × 66.38 mm |
| Through aperture | 110.32 × 62.28 mm |
| Bevel depth | 2.05 mm |
| Bevel angle | 45° |

#### Dual-display integration audit (Sunton + Waveshare)

- The rolled-back `Radio Enclosure Front - Proto v68` state was inspected without saving or moving its timeline marker. The original Sunton mechanical model is `5Inch_LCD_Model v1:2`, not the later generic `5" LCD IPS Display v7:1` occurrence.
- Measured Sunton interface: 120.7 × 75.7 mm front glass, 110.0 × 66.0 mm active area, 136.7 × 84.0 mm PCB, four approximately Ø3.1 mm through-holes on a 129.7 × 76.8 mm pitch, and approximately 5.5 mm from the glass face to the PCB mounting plane.
- Measured Waveshare `5-DSI-TOUCH-A` interface and checked it against the Waveshare drawing: 129.0 × 72.8 mm front package with R4 corners, 110.32 × 62.28 mm active area, 5.6 mm front-package depth, and eight M2.5 rear threads. The symmetric outer four are on a 117 × 61 mm pitch; the offset inner four are the 58 × 49 mm Raspberry Pi pattern and should remain available for the Pi rather than being consumed by the enclosure mount.
- The currently linked Waveshare occurrence is only positioned for visual reference. Its front surface is about 10 mm behind the enclosure front, and no Waveshare seating pocket, gasket ledge, retainer, or mounting adapter exists yet.
- The former 121.1 × 76.2 mm through-aperture was the old Sunton glass-clearance opening. It cleared the 120.7 × 75.7 mm Sunton glass by roughly 0.2/0.25 mm per side, but was 3.4 mm taller than the 72.8 mm Waveshare glass and therefore could not neatly frame the Waveshare package.
- A single close-fitting full-glass pass-through cannot serve both displays because the Sunton is narrower/taller while the Waveshare is wider/shorter. The clean master-model solution is two display configurations driven from the same display datum and shell: `SUNTON` retains the original glass clearance and direct four-boss mount; `WAVESHARE` uses an active-area window, rear glass pocket, compliant gasket, and a removable retainer/adapter using the Waveshare outer four M2.5 threads.
- If one physically identical printed front shell must accept either display, use a common approximately 110.7 × 66.4 mm viewing window plus a rear pocket sized for the union envelope (approximately 129.5 × 76.2 mm with printing clearance) and separate Sunton/Waveshare locating-retainer parts. This exposes about 2.1 mm of inactive black glass above and below the Waveshare active area but safely retains both glass envelopes.
- The Waveshare active-area reference is centered at X = -18.5246 mm, Z = 11.7106 mm. `SK_FRONT_DISPLAY_BEVEL` and `SK_FRONT_DISPLAY_APERTURE` are now fully constrained and genuinely driven by the `disp*` parameters; the previous fixed rectangles ignored parameter-table edits. Add separate named parameters for glass envelope, mount pitch, face recess, pocket clearance, gasket compression, and adapter thickness when the mounting pocket and retainer are implemented.

### Button layout

- Button profile: 10 × 5 mm with 0.5 mm corner radius.
- Top row: six buttons, first center `(-62.65, -46.35)`, 18 mm X pitch.
- Left grid: 2 × 4, first center `(-113, 0.66)`, 15 mm X pitch and 12 mm Z pitch.
- Extra left button center: `(-98, 48.66)`.
- Right grid: 3 × 4, first center `(61.5, 3.66)`, 15 mm X pitch and 12 mm Z pitch.

### Circular controls

| Center X, Z (mm) | Through diameter | Recess diameter |
| --- | ---: | ---: |
| `(-106, -46)` | 15.8 mm | 19 mm |
| `(-106, -22)` | 8.4 mm | 15 mm |
| `(76.519, -33.6)` | 8.85 mm | 16 mm |
| `(113, 2.9983)` | 6.8 mm | 14.6 mm |
| `(113, 39.9983)` | 6.8 mm | 14.6 mm |
| `(-108.9894, 52.1731)` | 3.5 mm | None |

### Mating lip and notches

- Lip outer boundary: 250 × 126 mm.
- Lip inner boundary: 246 × 122 mm.
- Lip ring width: 2 mm.
- Lip begins at depth 24.04 mm.
- Notch taper spans depth 26–28 mm and peaks at 27 mm.
- Twelve notches total: three per edge.
- Top/bottom notch centers X: `-100`, `0.5`, `101` mm.
- Left/right notch centers Z: `-38`, `0`, `38` mm.
- Nominal notch width: 10 mm.
- Top/bottom peak depth: 0.8343 mm.
- Left/right peak depth: 0.7929 mm.

### Back half

| Item | Value |
| --- | ---: |
| Back envelope | 254 × 130 × 30 mm |
| Front-most Y coordinate | 24.04 mm |
| Rear exterior Y coordinate | 54.04 mm |
| Main rear-wall thickness | 4 mm |
| First mating opening | 250 × 126 mm |
| Main cavity opening | 246 × 122 mm |
| Mating-groove depth | 6.10 mm |
| Rear edge radius | 1.9 mm |
| Back snap detents | 12 total, three per wall |
| Detent base | 10 × 2 mm, 45° taper |
| Detent crown | R0.4 mm, 0.8343 mm peak projection |
| Rear label height | 4 mm |
| Rear AMS inlay depth | Shared `labelDepth = 0.6 mm` |

The rear connector interface reproduces the WIFI circular port and counterbore, USB opening and recess, exact DB9 aperture with its two screw holes and inner/outer recesses, COM 0 opening, end circular connector and counterbore, plus the four 6 mm panel holes.

## Fusion Sketch Structure

| Sketch | Purpose | Status |
| --- | --- | --- |
| `SK_PANEL_PROFILE` | Centered outer panel master | Complete; fully constrained |
| `SK_DISPLAY_OPENING` | Front display opening | Complete; fully constrained |
| `SK_DISPLAY_APERTURE` | Smaller through aperture | Complete; fully constrained; normally hidden |
| `SK_BUTTON_MASTERS` | Four seed profiles for later feature patterns | Complete; fully constrained |
| `SK_ROTARY_THROUGH` | Six circular through-cut profiles | Complete; fully constrained |
| `SK_ROTARY_RECESSES` | Five counterbore/recess profiles | Complete; fully constrained |
| `SK_LABELS` | 31 native editable front-panel labels | Complete; native text with parameterized height |
| `SK_LIP_BASE` | Outer and inner mating-lip boundaries | Complete; fully constrained |
| `SK_INNER_CAVITY` | Independent front-thickness and side-wall cavity | Complete; fully constrained |
| `SK_LIP_RELIEF` | Rear perimeter relief that leaves the mating lip | Complete; fully constrained |
| `SK_LIP_NOTCH_TB_BASE` | 10 × 2 mm top/bottom tapered-pocket seed | Complete; fully constrained |
| `SK_LIP_NOTCH_LR_BASE` | 10 × 2 mm left/right tapered-pocket seed | Complete; fully constrained |
| `SK_MOUNT_BOSSES_SHORT` | Eleven short internal mounting-boss profiles | Complete; fully constrained |
| `SK_MOUNT_BOSSES_TALL` | Four tall encoder-board mounting-boss profiles | Complete; fully constrained |
| `SK_MOUNT_PILOTS_STANDARD` | Six linked standard blind M3 pilot profiles | Complete; fully constrained; projected from boss centers |
| `SK_MOUNT_PILOT_POWER` | Linked left-power blind M3 pilot profile | Complete; fully constrained; projected from boss center |
| `SK_MOUNT_PILOTS_FKEY` | Four linked function-key blind M3 pilot profiles | Complete; fully constrained; projected from boss centers |
| `SK_MOUNT_PILOTS_ENCODER` | Four linked encoder-board blind M3 pilot profiles | Complete; fully constrained; projected from boss centers |
| `SK_BACK_OUTER_PROFILE` | Centered back envelope | Complete; fully constrained; driven by `backWidth` and `backHeight` |
| `SK_BACK_GROOVE_OPENING` | First-stage 250 × 126 mm mating opening | Complete; fully constrained; parameter driven |
| `SK_BACK_MAIN_CAVITY` | Main 246 × 122 mm cavity | Complete; fully constrained; parameter driven |
| `SK_BACK_PORTS_THROUGH` | WIFI, USB, DB9, COM 0, end connector, and panel through-holes | Complete; locked connector-reference geometry |
| `SK_BACK_PORT_RECESSES` | WIFI counterbore | Complete; locked connector-reference geometry |
| `SK_BACK_USB_RECESS` | USB exterior relief | Complete; locked connector-reference geometry |
| `SK_BACK_END_CONNECTOR_RECESS` | End-connector counterbore | Complete; locked connector-reference geometry |
| `SK_BACK_DB9_OUTER_RECESS` | DB9 exterior rounded recess | Complete; locked connector-reference geometry |
| `SK_BACK_DB9_INNER_RECESS` | DB9 interior rounded recess | Complete; locked connector-reference geometry |
| `SK_BACK_DETENTS_TOP` | Three top snap-detent bases | Complete; locked verified mating geometry |
| `SK_BACK_DETENTS_BOTTOM` | Three bottom snap-detent bases | Complete; locked verified mating geometry |
| `SK_BACK_DETENTS_RIGHT` | Three right snap-detent bases | Complete; locked verified mating geometry |
| `SK_BACK_DETENTS_LEFT` | Three left snap-detent bases | Complete; locked verified mating geometry |
| `SK_BACK_LABELS_NATIVE` | WIFI, USB, RS232, and COM 0 native rear text | Complete; separate editable text sketch |

The button and notch sketches intentionally contain only master profiles. Repetitions should be model-feature patterns rather than sketch patterns to keep regeneration fast.

## Completed

- Inspected `Front_Half.step`, `Back.step`, and `Front.dxf`.
- Measured the overall panel, display, controls, lip, overlap, and notch layout.
- Added or corrected design-driving user parameters in Rev2.
- Created the separate, fully constrained mechanical master sketches listed above.
- Separated through holes from larger front recesses.
- Separated the mating lip and notch seeds from the front-panel sketches.
- Kept labels in their own dedicated sketch.
- Reconstructed 31 semantic labels as native Fusion text instead of retaining 699 DXF outline splines.
- Created the 254 × 130 × 30 mm `Front_Rebuild` base body.
- Applied the 1.9 mm outer corner fillets as model features.
- Created the inner cavity with independent 3 mm front thickness and 4 mm wall thickness.
- Cut the Waveshare active-area aperture at 110.32 × 62.28 mm and retained the parameter-driven 2.05 mm, 45° bevel, producing a 114.42 × 66.38 mm front opening.
- Created all 27 rounded button openings from four seeds and three rectangular model patterns.
- Created the six circular through-holes in one grouped feature.
- Re-measured and created the five front recesses: 19 mm and 16 mm at 2 mm depth; 15 mm and 14.6 mm at 1.5 mm depth.
- Created the 5.96 mm rear perimeter relief, leaving the verified 250 × 126 mm outer lip boundary.
- Reconstructed all twelve mating notches as 45° tapered pockets with true full-round crowns.
- Patterned three notches per edge and mirrored the two seed families to the opposing edges.
- Validated the generated crown radii against the STEP: approximately 0.400035 mm top/bottom and 0.499984 mm left/right.
- Validated the completed lip against `Back.step` using Fusion interference analysis.
- Original `Front_Half.step`/`Back.step` interference: 8.572407 mm³.
- Rev2/`Back.step` interference: 8.572355 mm³.
- Difference: 0.000052 mm³, confined to the same twelve-notch envelope; this confirms intentional mating preload rather than an accidental collision.
- An earlier orientation review relied on Fusion's named Front view and incorrectly concluded the global axes were corrected. The later model-space audit supersedes that conclusion.
- Confirmed that the required correction is a rigid 180° orientation change about the depth/Y axis, not a geometric mirror.
- Verified the transform in an unsaved linked-occurrence proof of concept: `POWER` and `SHIFT` move to positive Z, `F1`–`F6` to negative Z, and the rear labels become 12.81 mm above their connector centers.
- Added `labelDepth = 0.6 mm` and `labelInlayRecess = 0 mm` manufacturing parameters.
- Calibrated all 31 native front labels against `Radio Enclosure Front - Proto v66`. Although v66 reports a nominal 2.8 mm text height, its evaluated `POWER`, `TUNE`, and `SHIFT` bounds are approximately 14.86 × 2.95, 10.93 × 2.85, and 11.83 × 2.91 mm. Current-engine Arial at `frontLabelHeight = 4 mm` reproduces those bounds closely and is more reliable with a 0.4 mm nozzle.
- Restored the v66 display spacing in `AF / RF`, `A / B`, `BND +`, and `BND –` while retaining the corrected `NTCH` string and every existing semantic label center.
- Added the single grouped `FT_LABEL_DEBOSS_CUT` feature at the end of the master timeline; it remains suppressed during normal mechanical editing.
- Added `FT_AMS_WHITE_TEXT_INLAY` directly after the deboss feature in the mechanical master. It creates 105 named white glyph bodies from the same 31 native `SK_LABELS` text objects and remains suppressed during normal editing.
- Corrected the legacy label content from `INT CH1` to `NTCH` and audited all 31 label strings.
- Corrected `WIDTH` and `AF / RF` to the original right-side stack: `WIDTH` frame center at local sketch `(-113, 27.5983)` mm and `AF / RF` at `(-113, 16.4445)` mm.
- Created an isolated AMS print-preparation design with `BLACK_FRONT` and `WHITE_TEXT_INLAY` components, oriented upright in the named Front view.
- Added parametric `FT_AMS_BLACK_LABEL_CUT` and `FT_AMS_WHITE_TEXT_INLAY` features in print prep; both are driven by the shared `labelDepth`, `labelTextHeight`, and `labelInlayRecess` parameters.
- Generated 105 disconnected white glyph solids from the same 31 native text definitions used for the black cavities.
- Validated AMS material replacement: black volume 136,025.007192 mm³ plus white volume 237.935212 mm³ equals 136,262.942403 mm³, differing from the unlettered master by only 0.00000035 mm³.
- Parameter-change validation passed: changing `labelDepth` from 0.6 to 0.8 mm updated both black and white features without warnings while preserving the same combined solid volume; the value was restored to 0.6 mm.
- Consolidated the final AMS workflow into the mechanical master so enclosure and label changes have one source of truth. The separate print-preparation design is retained only as a historical recovery checkpoint.
- Revalidated the consolidated master with both print features enabled: 106 bodies total, 2,011 faces on `Front_Rebuild`, black volume 136,025.007192 mm³, 105 white bodies totaling 237.935212 mm³, and combined volume 136,262.942403 mm³.
- Suppressed both print features after their initial validation. Before internal mounts were added, the normal editing state was one body with 320 faces and volume 136,262.942403 mm³.
- Organized the two print-only features in the collapsed timeline group `PRINT - AMS LABELS`.
- Renamed all 105 generated inlay bodies semantically by label, character order, and character, for example `INLAY_F1_01_F`, `INLAY_BND_MINUS_04_MINUS`, and `INLAY_AF_SLASH_RF_03_SLASH`. The naming operation does not move or alter the geometry.
- Reconstructed all 15 original internal mounting bosses using the fully constrained short- and tall-boss sketches, with linked pilot sketches separated by blind-hole depth family.
- Added named parameters for the 6.4, 6.5, 7.0, and 7.5 mm boss diameters; 8.2 and 11.04 mm boss heights; 2.529 mm tap-drill diameter; and the four retained blind-hole base thicknesses.
- Reproduced the original lightweight thread specification as one grouped cosmetic thread feature: ISO metric M3×0.5, class 6H, right-handed, full hole length, and not physically modeled.
- Organized the six mounting sketches, six boss/pilot features, and thread feature in `MOUNTING - INTERNAL BOSSES + M3 THREADS` immediately before the print-only group.
- Validated all 15 centers, outside radii, heights, tap-drill radii, and blind-hole depths against `Radio Enclosure Front - Proto v65`: maximum measured deviation 0.000000 mm.
- Validated the net boss material addition: expected 4,678.227021542 mm³ and generated 4,678.227021542 mm³, with 0.000000000 mm³ difference.
- Reconstructed the back as the independently named `BACK_SHELL` body in the same Fusion Part document, avoiding an externally linked print or assembly document.
- Created the fully constrained, parameter-driven outer, groove, and main-cavity sketches. A live rebuild test changed `backWidth` from 254 to 255 mm and back to 254 mm with no feature warnings and the body envelope followed exactly.
- Recreated the two-stage 2 mm/4 mm mating wall, 4 mm rear wall, 1.9 mm outer/rear fillets, and the complete rear connector interface from `Back.step`.
- Recreated all twelve rear snap detents from four small seed sketches using 45° tapered extrusions and R0.4 crowns, then joined only those tool bodies to `BACK_SHELL` so the front body cannot be accidentally merged.
- Validated the new native front/back interference at 8.571944823 mm³ across 12 latch zones. The original STEP pair measures 8.572407877 mm³, a difference of only 0.000463054 mm³ (0.0054%).
- Added native 4 mm rear labels (`WIFI`, `USB`, `RS232`, and `COM 0`) in the separate `SK_BACK_LABELS_NATIVE` sketch.
- Implemented the rear labels with the same AMS workflow as the front: `FT_BACK_LABEL_DEBOSS_CUT` and `FT_BACK_AMS_WHITE_TEXT_INLAY`, sharing `labelDepth` and `labelInlayRecess`.
- Generated and semantically named 16 aligned rear inlay bodies (`INLAY_BACK_*`) and applied the validated `ABS (White)` front-inlay appearance.
- Validated the rear material interface at both 0.6 and 0.8 mm label depth. Black plus white combined volume remained exactly 197,171.517950408 mm³, and the parameter was restored to 0.6 mm.
- Organized the back mechanics and print-only features in the collapsed timeline groups `BACK HALF - PARAMETRIC REBUILD` and `PRINT - AMS BACK LABELS`.
- Preserved the reusable native rebuild script at `Back_Parametric_Rebuild.py` in the project workspace.
- Compared the exposed perimeter treatment directly against `Radio Enclosure Front - Proto v66`. The prototype uses matching R1.9 mm edge fillets on the front exterior at Y=0 and the back exterior at Y=54.04; Rev2 previously had the back fillet but left the front perimeter sharp.
- Replaced the sequential outer-corner and exposed-face fillets with one eight-edge setback feature per half: `FT_FRONT_COMBINED_SETBACK_FILLET` and `FT_BACK_COMBINED_SETBACK_FILLET`. Each combines the four depth-parallel corners with the four exposed-face perimeter edges, matching the construction order used by prototype `Fillet1` and `Fillet2`.
- Set both combined features to `isRollingBallCorner = false` and drove them from the shared `outerCornerR = 1.9 mm`; `backCornerRadius` is linked to `outerCornerR` so the halves cannot drift apart.
- Verified exact prototype corner topology on both halves: setback NURBS patch extents 3.799713078 × 3.799713078 × 3.799713078 mm and area 22.851383850 mm². The adjoining R1.9 cylindrical runs also match the prototype bounding extents and face areas.
- Linked `backWidth = caseWidth`, `backHeight = caseHeight`, and derived the 250/246 mm back openings from those shared dimensions. A regeneration test changed `caseWidth` from 254 to 255 mm: both bodies became exactly 255 mm wide, both setback patches remained numerically unchanged and healthy, and no feature reported a warning. `caseWidth` was restored to 254 mm.

## Functional Parity Status

Rev3 now contains native front and back enclosure halves with the original snap-fit behavior. Against the main front body in `Radio Enclosure Front - Proto v66`, the previously missing non-display support geometry has been accounted for by the five recreated rotary/control collars. Display mounting/support hardware remains deliberately deferred.

### Reconstructed and validated

- Overall enclosure envelope, wall depth, front thickness, and external corner radii.
- Display opening and bevel.
- Button openings, circular control holes, and front recesses.
- Mating lip, all twelve notches, and the original front/back preload behavior.
- Front-view geometry and handedness match the source after applying the audited rigid transform, but the native Rev2 sketch/global-axis orientation remains to be rebuilt.
- All 31 label strings and placements as separate, editable native sketch text.
- All 15 internal component-mounting bosses, blind pilot holes, and original M3×0.5 6H thread metadata.
- Five rear rotary/control support collars, including the stepped AF/RF collar, as parameter-driven joined features.
- Clean parametric organization using small constrained sketches and model-feature patterns.
- Complete native back shell, rear connector openings/recesses, rear edge treatment, and twelve-detent mating system.
- Rear labels using the same black-deboss/white-AMS-inlay manufacturing interface as the front.
- Rear legends read upright in the normal exterior rear view and are centered on the `WIFI`, `USB`, `RS232`, and `COM 0` connector centerlines. They remain above the openings so attached cables are less likely to obscure them.

### Not yet functionally reproduced

- Internal display mounting/support features: the Waveshare carrier, glass pocket and enclosure posts now exist and are audited (see the 2026-09-02 carrier section); constrained-sketch cleanup of the script-generated feet/knob sketches is still open.
- Any supports belonging to separate legacy components rather than the v66 main front body will be evaluated when those components are brought into V3.

The v66 main front body was checked for the previously suspected button-guide tunnels, local ribs, and pads. The rectangular button apertures terminate at the front wall and no additional main-body guide tunnels were found, so V3 intentionally does not add speculative geometry.

### Label manufacturing workflow

- The enclosure is printed in PLA on a Bambu Lab A1 with AMS Lite; the white lettering is produced during the print rather than filled manually afterward.
- The legacy main front body has 105 planar glyph-floor faces at 0.5 mm behind the outer front surface, confirming a 0.5 mm deboss depth.
- The legacy Fusion document also contains dozens of permanently active white glyph bodies. These materially contribute to its browser and regeneration complexity.
- Rev2 keeps the same manufacturing capability in the mechanical master using two normally suppressed, adjacent parametric features: `FT_LABEL_DEBOSS_CUT` and `FT_AMS_WHITE_TEXT_INLAY`.
- Both features are generated from the same native `SK_LABELS` text and use `frontLabelHeight = 4.0 mm`, `labelDepth = 0.6 mm`, and `labelInlayRecess = 0 mm`. The deboss and inlay therefore retain one aligned text source without document synchronization.
- Normal editing workflow: keep both print features suppressed. With the internal bosses present, this leaves one body with 380 faces and avoids the everyday cost of the 105 glyph bodies.
- The collapsed `PRINT - AMS LABELS` timeline group contains both features. Expand it only when editing or preparing an AMS export.
- The rear uses the equivalent adjacent features in `PRINT - AMS BACK LABELS`, with 16 `INLAY_BACK_*` bodies. Both front and back share `labelDepth` and `labelInlayRecess`. Rear orientation and centering are defined in `SK_BACK_LABELS_NATIVE`; the deboss and inlay features consume that same sketch without corrective downstream moves.
- AMS export workflow: enable the applicable front/back print groups, export each black enclosure body with its aligned `INLAY_*` bodies as multipart 3MF, assign black and white AMS filaments in Bambu Studio, then suppress the print groups again for normal editing.
- The saved `ARCI Enclosure Rev2 - AMS Print Prep v1` document is historical only. It may be kept, archived, or closed without affecting the maintained Rev2 design.

### V3/V4 front-label match to prototype v66

- The front sketch `SK_FRONT_LABELS_NATIVE` uses native Arial Bold text. The 28 general labels are driven by `frontLabelHeight = 4 mm`; the four compact dual-encoder legends use `encoderLegendHeight = 3 mm`. Prototype v66 was verified to use `TextStyleBold`; regular Arial was the cause of V3's thin strokes.
- The current Fusion text engine produces smaller evaluated glyphs than the legacy v66 engine at the same nominal height. A 4 mm V3 height was therefore chosen from measured geometry, not from the legacy 2.8 mm nominal value.
- Calibrated current-engine bold bounds are: `POWER` 14.798828 x 2.960938 mm, `TUNE` 10.603515 x 2.912109 mm, and `SHIFT` 11.328125 x 2.962891 mm. The respective v66 references are 14.856507 x 2.949279 mm, 10.930696 x 2.847749 mm, and 11.829717 x 2.910702 mm.
- Legacy spacing was restored in `AF / RF`, `A / B`, `BND +`, and `BND ` plus U+2013 EN DASH. The en dash is constructed from its Unicode code point in the rebuild/update scripts to prevent transport encoding corruption.
- Before the dual-encoder legend revision, the bold rebuild retained 106 front bodies (`FRONT_SHELL` plus 105 inlay bodies); the remapped sixth `AF / RF` contour used the same `ABS (White)` appearance as the other inlays.
- In the active `ARCI Enclosure Rev3 v12`, the 27 rectangular-button labels remain 0.40 mm above the v66-matched placement. `buttonLabelOffset` is 5.15 mm, and the measured land between the evaluated text outline and each 10 x 5 mm opening is 1.168-1.219 mm.
- The VFO through-hole, 16 mm front recess, primary support collar, and collar counterbore are now driven from `vfoCenterX = rightButtonMatrixCenterX` and `vfoCenterZ = -33.6 mm`. All six concentric VFO circle definitions solve at X = 76.500 mm, exactly on the center column of the 3 x 4 right button matrix; the former 0.019 mm discrepancy has been removed.
- An interim V12 layout used single-line `SHIFT`—⊙—`WIDTH` and `AF`—⊙—`RF` legends with 0.6 mm leaders. It only fit at 3 mm text (≈0.45 mm stems, one 0.4 mm extrusion line) and `WIDTH` ended 0.710 mm before the right edge fillet; the enclosure cannot grow because 254 mm already fills the 256 mm Bambu Lab A1 bed.

### V12 dual-encoder legend decision (2026-09-02, A1 / 0.4 mm nozzle)

- Two graphic variants were evaluated in the live model and rejected on appearance: the single-line concentric symbol with leaders (above) and a two-row dot/ring legend (`● SHIFT / ○ WIDTH`, `● AF / ○ RF`, 4 mm words left-aligned after a symbol column). Neither reads well at panel scale, and the symbol geometry (0.6 mm leaders, 0.7–0.85 mm ring strokes) is the least robust feature on a 0.4 mm nozzle.
- Final layout: the original v66 word-only stack, all 4 mm Arial Bold centered on `encoderLegendCenterX = rightDualEncoderCenterX` (113 mm): `SHIFT` at `encoderUpperLegendZ = 50.998977` above the upper encoder, `WIDTH` at `encoderWidthLegendZ = 27.598299` below it, and `AF / RF` at `encoderLowerLegendZ = 16.444501` above the lower encoder. `encoderLegendHeight = frontLabelHeight`.
- Measured extents: `SHIFT` X 107.34–118.66 / Z 49.52–52.48; `WIDTH` X 106.61–119.39 / Z 26.17–29.03; `AF / RF` X 106.09–119.91 / Z 14.96–17.92. Widest word ends 5.2 mm before the right edge fillet; `WIDTH` sits 3.7 mm below the upper recess; `AF / RF` leaves 4.7 mm of land above the lower recess.
- The separate `AF`/`RF` texts and their `FT_FRONT_DUAL_ENCODER_RF_DEBOSS/_INLAY` features were removed and the single `AF / RF` text restored, so `SK_FRONT_LABELS_NATIVE` again holds 31 texts consumed by the standard front deboss/inlay features. All `SK_FRONT_DUAL_ENCODER_SYMBOL_*` sketches and `FT_FRONT_DUAL_ENCODER_*` features are deleted.
- The active front has 106 valid bodies and no unhealthy features. The edits are intentionally left unsaved for visual approval. `Front_Parametric_Rebuild.py` matches this layout; the orphaned `encoderSymbol*`, `encoderUpperSymbolX`, `encoderLowerSymbolX`, `encoderLegendRowPitch`, and `encoderSymbolTextGap` parameters may be deleted from the document.
- A1 print note: at 254 mm the front must be sliced with skirt and brim disabled; the labels print face-down as 3 × 0.2 mm layers, so first-layer squish slightly fattens white strokes—one more reason to keep every label at the 2.9 mm cap height rather than smaller.

### Front-label printability audit and letter spacing (2026-09-02, A1 / 0.4 mm nozzle)

- Audit of the 31 labels before the change: cap height 2.86–2.96 mm, `I` stems 0.58 mm, smallest counters 0.66 mm (`B`, `4`) / 0.73 mm (`R`), 1.17–1.22 mm land between text and every 10 × 5 mm button opening, ≥3.5 mm between words in a row, 0.6 mm = three 0.2 mm layers of inlay. All acceptable for a 0.4 mm nozzle.
- The one failing feature was the black wall *between letters*: true minimum outline-to-outline gaps of 0.09 mm (`X–V`, `V–T` in `XVTR`), 0.17 mm (`T–T` in `ATT`) and 0.27–0.32 mm (`SHIFT`, `WIDTH`, `XIT`, `RIT`, `POWER`, `PWR`, `AF / RF`, `PRE`). Below one 0.42 mm line the slicer cannot lay black between the letters, so they print fused.
- Fix: character spacing. The legacy `createInput` texts expose no spacing, so all 31 labels were recreated as multi-line texts (`createInput2` + `setAsMultiLine`, center/middle alignment) with `frontLabelSpacingPct = 18`. In the multi-line engine `height` is the true cap height, so `frontLabelHeight` is now **2.9 mm** (the same evaluated cap as before; the old 4 mm nominal belonged to the legacy engine). `encoderLegendHeight = frontLabelHeight` still.
- Result: stems 0.59 mm, counters ≥0.67 mm, smallest letter gap **0.44 mm** (`XVTR`), median 0.90 mm; land to button 1.12–1.21 mm; tightest word gap 2.98 mm (`TUNE`|`PROC`). Widths grew ~0.34 mm per gap (e.g. `POWER` 14.80 → 16.38 mm, `WIDTH` 12.79 → 14.35 mm, still 4.9 mm clear of the right edge fillet). All label centers were preserved.
- `FT_FRONT_LABEL_DEBOSS_CUT` and `FT_FRONT_AMS_WHITE_TEXT_INLAY` were recreated from the new texts with identical expressions; they now sit at the end of the timeline rather than inside the `PRINT - AMS FRONT LABELS` group (which still holds the sketch). 106 bodies, no unhealthy features, 105 inlay bodies renamed `INLAY_FRONT_<label>_<nn>_<char>` with the `PLA (White)` appearance.
- API notes for future scripting: `SketchText` proxies from `add()` go stale after further sketch edits (re-read `sk.sketchTexts` before building extrude inputs); the MCP wraps each script in one transaction that rolls back on exception; creating the two label extrudes in the same transaction as the text deletion/creation fails with "Some input argument is invalid"—run text creation, cut, inlay, and legacy deletion as separate calls.
- Follow-up: spacing raised to **22 %** for extra margin on the `X–V`/`V–T` pairs, and the power LED hole was made parametric (`ledHoleX = -112 mm`, `ledHoleZ = 52.1731 mm`, diameter `auxHoleD`) and moved 3.0 mm left from its original PCB-coaxial position (−108.9894) so the wider `POWER` word keeps clear land. The LED does not need to be coaxial with the PCB part. `SK_FRONT_ROTARY_THROUGH` remains fully constrained.
- Unsaved, pending visual approval.

### V4 rear-label typography match to prototype v66

- Prototype v66's `RS232 Back` sketch was verified to use 4 mm `Artifakt Element Extra Bold` with `TextStyleBold`. V4 previously used Arial Regular because the rebuild script assigned a non-functional `isBold` attribute.
- `SK_BACK_LABELS_NATIVE` now uses the verified v66 font and native bold style for `WIFI`, `USB`, `RS232`, and `COM 0`; the four existing connector-centered label positions and orientation were preserved exactly.
- Fusion's current text engine retains the same approximately 2.86-2.96 mm evaluated cap height but produces narrower character advances than the legacy v66 text engine. Word size was intentionally not increased because this change addresses stroke weight while preserving the established connector-centered layout.
- Both rear print features regenerated successfully and remain enabled. Final audit found 17 rear bodies (`BACK_SHELL` plus 16 semantically named `INLAY_BACK_*` bodies), 16 `ABS (White)` appearances, no generic or temporary body names, and no invalid bodies.
- `Back_Parametric_Rebuild.py` now creates the v66 rear typography natively and searches the full design for the validated front white-inlay appearance.

### Button labels driven by `buttonLabelOffset` (2026-09-02)

- Slicer preview showed the label cavities' wall loops fusing with the button-opening loops: only 1.12–1.21 mm of land, while two wall pairs need ≈1.7 mm. The 27 button labels were therefore raised and, at the same time, made parametric.
- Each button label's 30 × 6 mm multi-line text box is now dimensioned from the sketch origin: top corner `<btnZ> + buttonLabelOffset + 3 mm`, bottom corner `<btnZ> + buttonLabelOffset − 3 mm`, and X `<btnX> + 15 mm` (magnitudes, since sketch x = −X and y = −Z). 81 dimensions in `SK_FRONT_LABELS_NATIVE`; the four encoder legends and `MULTI` remain free. Pinning both corners is required — with only the top corner pinned the solver stretches the box and the middle-aligned text moves by half the intended amount.
- `buttonLabelOffset` changed 5.15 → **5.9 mm** from the Parameters dialog. Measured: label centers 5.88–5.91 mm above their buttons, land below 1.90–1.95 mm, gap above to the next row's button ≥2.10 mm. `Front_Parametric_Rebuild.py` (`anchor_button_labels`, `BUTTON_CENTERS`) reproduces the anchoring.

### VFO main dial knob (2026-09-02)

- New component `KNOB_VFO_MAIN` in the master, modeled on the Yaesu FT-710 main dial and driven by `vfo*` parameters. It sits on the Copal RMS20-250-201-1 encoder at `vfoCenterX/Z` (Ø6 mm D-shaft, 4.5 mm across the flat facing +X, shaft tip 14.5 mm in front of the panel, Ø9 bushing protruding 2 mm).
- Geometry: `vfoKnobD = 44 mm`, `vfoKnobL = 21 mm`, 1 mm panel gap (`vfoKnobGap`). **Diamond knurl** (the first straight-groove version was rejected): the 96-tooth star profile `SK_VFO_KNURL_PROFILE` (`vfoKnurlTeeth`, 1.44 mm pitch, `vfoKnurlDepth = 0.5 mm`) is **swept along the axis with a twist** of +27.1° (`FT_VFO_KNURL_RH`) and −27.1° (`FT_VFO_KNURL_LH`), and the two bodies are intersected (`FT_VFO_KNURL_DIAMOND`). The twist follows from `vfoKnurlHelixDeg = 30°` over the 18 mm skirt, so the pyramids form with three features instead of a 192-instance helical pattern. A ruled loft between rotated star sections was tried first and does not work: Fusion matches each tooth to its nearest counterpart, so a 7.2-tooth twist collapsed to a 0.75° residual and the ridges stayed axial. Then a 3 mm smooth bezel band with a 1.5 mm chamfer; Ø36 × 0.4 mm face recess; Ø9 finger cup 3.5 mm deep at 12.5 mm radius with a rounded floor; Ø10.5 × 2.5 mm bushing counterbore; D-profile shaft bore Ø6.15 × 14 mm (flat offset 1.55 mm); Ø2.5 M3 grub-screw pilot at 9 mm behind the back face, entering on the flat side. 5,772 faces (the diamond facets dominate); keep the component normally hidden or suppressed while editing the enclosure.
- API note: `Sketch.modelToSketchSpace` on an offset construction plane returns an out-of-plane z for points not on that plane; zero it before creating curves, or the geometry silently becomes 3D sketch geometry at the model point (which made the first loft attempt fail as "coplanar sections").
- Nearest panel feature to the Ø44 envelope is the `CLR` button at 36 mm from the axis, so the knob has ≥14 mm clearance everywhere.
- **Two-part construction** (requested 2026-09-02): the knurled band is a separate rubber sleeve. `FT_VFO_GRIP_TUBE` (annulus Ø48 / Ø`vfoKnobD − 2·vfoGripWall` = Ø39, from 2 mm to 19 mm behind the panel) is intersected with the knurled knob (`FT_VFO_GRIP_FROM_KNURL`, tool kept) to give `KNOB_VFO_GRIP`, and that sleeve is then cut from the knob (`FT_VFO_CORE_MINUS_GRIP`, tool kept) to give `KNOB_VFO_CORE` with a Ø39 seat. The sleeve is captured between the core's `vfoGripBackLip = 1 mm` rear lip and the bezel; `vfoGripWall = 2.5 mm`. The sleeve body lives in child component `KNOB_VFO_GRIP`.
- Materials: core ABS Plastic / `PLA (Black)` with the bezel chamfer `Aluminum - Satin`; sleeve `Rubber, Black` / `Rubber - Soft`. Print the core back-down in ABS/PLA and the sleeve standing in TPU 95A (stretches ~13 % over the rear lip during assembly). 305 faces, healthy.
- Unsaved, pending visual approval.

### Waveshare display carrier audit and corrections (2026-09-02)

Audited `DISPLAY_CARRIER_WAVESHARE_ARCI` (four corner brackets), the rear glass pocket, the front aperture and the ARCI PCB placement in `ARCI Enclosure Rev3 v19`. The Waveshare 5-DSI-TOUCH-A drawing (129 × 72.8 R4 outline, 110.32 × 62.28 centred active area, 5.6 mm front package, 5.0 mm M2.5 female standoffs on 117 × 61 and 58 × 49 pitches) matches the linked `Waveshare_5_DSI_TOUCH_A v3` reference: glass front to standoff face = 10.62 mm.

Findings and fixes (all parameter-driven, unsaved):

- **ARCI standoffs were on the wrong holes.** `arciMountSpacingX/Z = 133.8 × 80.8` came from the PCB's R1.6 corner-radius arc centres; the real Ø3.2 mounting holes (full circle edges) are on **130.0 × 77.0 mm** (3.5 mm in from each edge, centre unchanged at `-17.74, 11.44`). Every standoff was 1.9 mm off in both X and Z. Parameters corrected; the tabs, standoffs and holes followed.
- **Carrier hole for the display was a 2.2 mm "pilot".** The display has female M2.5 standoffs, so `waveshareMountHoleDia` is now a **2.8 mm clearance** hole (M2.5 screw from the rear through the bracket).
- **Glass pocket was the old Sunton union envelope** (137.62 × 84.93, centred on the Sunton/ARCI centre), leaving the Waveshare glass 3.6–6.3 mm of float. It is now `SK_DISPLAY_WAVESHARE_GLASS_POCKET` / `FT_DISPLAY_WAVESHARE_GLASS_POCKET`: `waveshareGlassW/H + 2 × waveshareGlassFit (0.30)` = **129.6 × 73.4 mm centred on the Waveshare centre**, so the pocket locates the glass. The four Ø8 enclosure posts now sit fully on the 3 mm wall (previously their bases and pilot bottoms hung over the recess).
- **Aperture reveal.** The bevel bottom (2.05 deep) was 0.05 mm below the 2.0 mm pocket floor and only 0.05 mm per side larger than the active area. Now `dispBevelDepth = frontThickness − dispRecessDepth` (2.0) and `dispApertureW/H = waveshareActive + 2 × dispApertureReveal (0.50)` = 111.32 × 63.28 mm; front opening 115.32 × 67.28 mm. About 0.5 mm of black glass border shows per side so print and position tolerance cannot clip pixels.
- `carrierTabMargin` 3 → **4 mm** so the Ø8 standoffs no longer overhang the 2 mm plates and the Ø3.4 post holes keep a 2.3 mm wall.
- `arciPcbFrontY` now derives from the carrier stack (`carrierFrontY + carrierThickness + arciStandoffHeight` = 17.95 mm; was a stale 17.99).
- The separately imported root-level `ARCI v6:1` was at Y 35 and 1.9 / 1.1 mm off in X / Z; it was translated so its PCB front face sits on the standoffs and its holes coincide with them (verified from hole-circle centres at `(-82.74, -27.06)`, `(47.26, -27.06)`, `(47.26, 49.94)`, `(-82.74, 49.94)`).
- Stack (Y): pocket floor 2.0 → glass 2.01–7.63 → standoffs to 12.62 → 0.3 mm contact pads 12.65–12.95 → bracket 12.95–14.95 → Ø8 standoffs to 17.95 → ARCI PCB 17.95–19.42. Front-side IDC header pins reach Y 16.55, 1.6 mm clear of the bracket plates. Posts: Ø8 from Y 3 to 12.85 (0.1 mm gap), Ø2.7 blind M3 pilot to Y 3 → use M3×8–10 screws.
- Boolean intersection check shell / brackets / display bodies / ARCI PCB / ARCI front-side parts: **0 mm³ in every pair**. Timeline healthy.
- Front-shell volume after the pocket change: 149,548.6 mm³ (2,144 faces before the feet bosses).

### Tilt stand (2026-09-02, replaces the paddle feet)

- The first fold-down paddle feet were removed (components and the four bottom-wall bosses) after the full-assembly review: with a 54 mm deep, 130 mm tall box the centre of gravity passes over the rear edge at about 22° of tilt, so a front-only foot cannot be stable, and the 11.5 mm stow height left the rear unsupported.
- Replacement is a parametric rebuild of the user's `Tilt Feet ARCI v41` (Maestro-style stand: flat desk pad, radio pivots on a hinge carried by a bracket screwed to the rear panel), with the seven review items applied:
  1. `STAND_PAD` knuckle (Ø14 barrel, 12.8 wide) sits between two 4 mm `STAND_BRACKET` ears (clevis, double shear) instead of side-by-side knuckles. 24 castellation teeth (15° steps, `standTeeth`) on both knuckle faces and both ear faces lock the angle positively; the two sides always match.
  2. Pivot is 13 mm behind the rear panel (`standPivotBehind`) at Z −61 (`standPivotZ`), so tilting only lifts the enclosure; nothing swings into the pad. Pad top is 1 mm below the ear swing circle.
  3. Bracket plate bottom rests on the pad top at 0° and is the flat stop.
  4. Mount is 2 × M3 into Ø8 × 5 bosses inside the rear wall (`FT_STAND_BOSSES`, `FT_STAND_PILOTS`) at X ±109, Z −50 / −38, chosen to clear the end connector (X 102–112, Z −28 to −18) and the COM 0 legend. Countersunk 3.4 mm holes replace the 6 mm holes.
  5. Ø5.4 bore for a DIN 931 M5 × 30 partially threaded bolt; the 14 mm plain shank spans the rotating knuckle. The 8.2 AF × 3.5 hex-head pocket captures the head, with a DIN 125 washer and DIN 985 nyloc nut on the other side.
  6. Pad 30 × 100 × 6 mm with full-round ends, 60 mm in front of the pivot and 40 mm behind (`standPadRearReach`), two Ø28 × 3 stick-on rubber discs in 0.5 mm seats (modelled as `STAND_RUBBER_*` reference bodies). Ride height 12.5 mm at 0°.
  7. Stability: at 35° the centre of gravity is about 2 mm behind the pivot and at 45° about 15 mm, both inside the 40 mm rear reach; at 0° it is 40 mm in front, inside the 60 mm front reach.
- Left side is an identical translated copy, so the shared definition keeps both sides dimensionally synchronized. Zero Boolean overlap between bracket, pad and both shells. Script: `Tilt_Stand_Build.py`.
- Assembly ownership was cleaned up in `ARCI Enclosure Rev3 - CLEANUP v29`: `TILT_STAND_ASSEMBLY` is the sole top-level stand occurrence and contains two instances of the reusable `STAND_HINGE` definition. Each hinge owns `STAND_BRACKET`, `STAND_PAD`, one M5 fastener set, and two M3 bracket screws. `BACK_HALF` owns only the four integral mounting bosses and blind pilots. Timeline groups are collapsed and split by responsibility: `BACK HALF - STAND BOSSES AND PILOTS`, `STAND PARTS - BRACKET AND PAD`, `STAND HARDWARE - COMPONENT DEFINITIONS`, and `ASSEMBLY - TILT STAND`. Migration script: `Tilt_Stand_Assembly_Refactor.py`.
- Print the pad flat, the bracket on its mounting face; ream the Ø5.4 bores. Sketches are script-generated (unconstrained); dimensions live in the `stand*` parameters.

### Dual-concentric encoder knobs (2026-09-02)

- The two right-side encoders are Alps **EC11EBB24C03** dual-shaft parts: Ø7 bushing to Y −0.33, Ø6 hollow outer shaft to Y −8.0 with a 2 mm slot 4.5 mm deep across its end, Ø3.5 inner D-shaft (flat 0.71 from the axis, 7 mm long) to Y −18.5.
- Legacy `Knurled Knob (Bottom)` / `Knurled Knob Top` occurrences (14,507 and 20,112 faces each) are hidden, not deleted.
- Rebuilt to the supplier drawing of the real concentric pair (second image supplied 2026-09-02):
  - `KNOB_DUAL_OUTER_15`: Ø15 × 13.5 (2 mm C0.5 skirt, 9.5 mm knurl, 2 mm Ø14 top band with C1), **Ø10.2 × 4.5 top recess** (C1 → Ø12) that receives the inner knob's neck, Ø8 × 2 bushing relief underneath, Ø6.2 bore 8 deep (drawing 7; our shaft protrudes 7.4), two 1.7 × 4 drive-key stubs in the shaft slot, Ø4.2 web hole for the inner shaft, radial grub-screw pilot 4.5 above the underside (drawing M2 ⌀3.8; modeled as Ø2.5 for an M3 in PLA). 0.6 mm above the panel. 4,440 faces.
  - `KNOB_DUAL_INNER_11`: Ø6.5 × 4.5 neck nesting in the recess (0.3 mm axial clearance each way), Ø11 × 9.5 knurl body with C0.5, 1.5 mm Ø10 top band with C0.5 (→ Ø9 face), Ø3.6 bore 10 deep from the neck end (round for 2.2 mm, then D with the flat at 0.8), grub-screw pilot 6.5 above the neck end. 3,239 faces.
- Knurl is parametric: one 90° V groove (`knobOuterKnurlDepth` 0.3 / `knobInnerKnurlDepth` 0.28) is **swept along the axis with a twist** `knob*KnurlTwist = knurlH · tan(knobKnurlHelixDeg) / R` (30° helix → 41.9° / 57.1°) and circular-patterned **`knobOuterKnurlN = 60` / `knobInnerKnurlN = 44`** times (0.79 mm pitch, matching the fine knurl of the real parts); both hands give the diamond. Change the tooth count, helix angle or band height in the Parameters dialog and both hands regenerate. The V-groove profile itself is sketch geometry (depth is not a live parameter). A sweep along a fitted-spline helix fails intermittently with `ASM_SWEEP_ILLEGAL_SURFACE`; the twist sweep on the bare cylinder is reliable, so all internal features are cut afterwards, and the pattern axis is a construction axis from the cylinder face (a bare face reference failed validation).
- Appearance `Paint - Enamel Glossy (Black)` (no anodized-black entry in the library). Second pair placed at Z +37 for the upper encoder. Zero overlap against both encoder bodies, the shell and each other.
- Script: `Dual_Encoder_Knobs_Build.py` (deletes and rebuilds the `KNOB_DUAL_*` components). Because the first pair was deleted in the same unsaved session, the rebuilt components currently carry a `(1)` suffix (`KNOB_DUAL_OUTER_15 (1)`); Fusion keeps the deleted names reserved until the document is saved, so rename them after saving.
- Unsaved, pending visual approval.

### Quantitative solid comparison

After rigidly aligning `Front_Half.step` to the Rev2 coordinate system:

| Measurement | Value |
| --- | ---: |
| Rev2 solid volume | 140,941.169 mm³ |
| Original solid volume | 143,632.418 mm³ |
| Shared/overlapping material | 140,105.768 mm³ |
| Rev2 material outside the original | 835.401 mm³ |
| Original material absent from Rev2 | 3,526.650 mm³ |
| Rev2 material matching the original | 99.407% |
| Original material covered by Rev2 | 97.545% |

The updated values add the independently verified 4,678.227022 mm³ boss reconstruction to the prior Boolean comparison. The remaining `3,526.650 mm³` is accounted for by the five measured control collars, whose analytical annular volume is `3,526.6759 mm³`. The approximately `0.026 mm³` difference is within the tolerance of the STEP/Boolean measurement workflow. The older `835.401 mm³` Rev2-only figure is not being used as authority for V3 feature selection; functional comparison is against `Radio Enclosure Front - Proto v66`.

## Remaining Work

### 1. Review and promote the completed orientation remediation

- Inspect the active unsaved canonical document from the standard Front and Back views.
- Save it as the new master only after explicit approval; keep the linked assembly as a disposable transform reference.

### 2. Complete remaining reference geometry

- Reconstruct the display supports when the display phase resumes; the user explicitly deferred this work.
- Evaluate support geometry belonging to separate v66 components only when those components are intentionally migrated into V3.
- Keep repeated internal geometry grouped by subsystem and build it from constrained seed sketches plus model-feature patterns.
- Confirm whether any additional front-face detail is missing outside the measured panel controls during final component integration.
- Perform a final parameter and constraint audit; `SK_LABELS` placement frames are intentionally non-driving.

### 3. Complete final validation

- Compare overall extents and important faces against `Front_Half.step`.
- Section-check the native front and back together after any future mating-parameter edit.
- Preserve the verified 5.96 mm assembled overlap and 8.572 mm³ twelve-zone latch preload.
- Check display, button, rotary-control, and label positions against `Front.dxf`.
- Inspect for unintended interference, gaps, duplicate profiles, and unconstrained geometry.
- Record any deliberate clearance adjustment separately from source dimensions.

## Definition of Done

The reconstruction is complete only when:

- All required native sketches and labels are present and organized.
- Every design-driving sketch is fully constrained.
- Repeated geometry is implemented with model-feature patterns.
- The front body regenerates without warnings or broken references.
- Critical dimensions match the supplied STEP and DXF references.
- The front lip/notches and native back detents retain the verified original interference in a section check.
- Required internal component mounts and support geometry are present and verified against the reference.
- Labels are represented in the exported/manufactured solid with an explicitly chosen process and depth.
- Editing a primary parameter produces a predictable rebuild.
- A final saved Fusion version has been explicitly confirmed by the user.

## Next Action

Inspect the unsaved `ARCI Enclosure Rev3 v19` changes (corrected carrier standoff pattern, Waveshare-sized glass pocket, 0.5 mm aperture reveal, relocated ARCI board, tilt feet, dual-encoder knobs) and save a new version if approved. Print one carrier bracket and one foot module first to confirm the M2.5 clearance, the M3 pilots and the hinge tooth engagement in PLA.

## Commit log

2026-09-10 feat(cad): publish revision 3 of design & add printable parts
    [BACK_HALF.3mf, BACK_HALF.step, Back.step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]
2026-09-10 feat(fusion): add rebuild, audit, and export tooling
    docs: add printing, assembly, and project guides
2026-09-10 feat(cad): publish complete printable artifact set
    [BACK_HALF.3mf, BACK_HALF.step, BUTTON_CAP.3mf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]
